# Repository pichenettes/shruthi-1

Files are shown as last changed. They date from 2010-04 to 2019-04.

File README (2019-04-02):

Shruthi-1, a digital/analog hybrid MIDI monosynth.

This project is a redesign of the original Shruti-1, with a spec'ed up CPU,
and a focus on easy upgrades/modification of the analog section.
The ATMega644p allows new features in the firmware -- a larger selection of
oscillator algorithms, a bigger selection of wavetables, and a tiny sequencer.

Original developer: Emilie Gillet (emilie.o.gillet@gmail.com)

The firmware is released under a GPL3.0 license. It includes a
reimplementation of the formant synthesis algorithm used in Peter Knight's
Cantarino speech synthesizer.

The PCB layouts and schematics (in /hardware/shruthi/design/pcb)
are released under a Creative Commons cc-by-sa 3.0 license - except for some
discontinued filter boards which were released under a cc-by-nc-sa 3.0 license.

Documentation, analyses, simulations and 3D models are released under a
Creative Commons cc-by-sa 3.0 license.

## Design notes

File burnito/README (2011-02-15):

Burnito is a firmware for the Shruthi-1 digital board with a very specific
purpose: burn I2C eeproms with Shruthi-1 presets.

This firmware contains a large 16kb blob in flash with the eeprom contents. At
boot, it tries to recognize the size of the eeprom, and writes the relevant
part of this blob to the eeprom. Afterwards, the data is read back from the
eeprom and compared to the original.

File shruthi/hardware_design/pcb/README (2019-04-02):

PCB art:
- "saraswati" by Francois Barbut.
- "peacock_face" by Emilie Gillet.
- "radha" by Emilie Gillet.

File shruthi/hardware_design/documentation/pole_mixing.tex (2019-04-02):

\documentclass[a4paper,10pt]{article}
\usepackage[utf8]{inputenc}
\usepackage[T1]{fontenc}
\usepackage[english]{babel}
\usepackage{times}
\usepackage{graphicx}
\usepackage{tikz}
\usepackage{circuitikz}
\textwidth=6in
\textheight=9.0in
\headheight=0in
\headsep=0in
\oddsidemargin=0in
\evensidemargin=0in
\title{SSM2164 4-pole with pole-mixing}
\author{Émilie Gillet -- \tt emilie.o.gillet@gmail.com}
\date{}
\begin{document}

\maketitle

This document explains the inner workings of the ``Pole mixer" filter board, which uses a SSM2164 4-pole core along with a pole-mixer to realize 15 different transfer functions.

\section{VCA-based 1-pole LPF}

We remind here that a SSM2164 VCA cell works as a voltage-controlled current attenuator, according to the following equation:

$$i_{out} = i_{in} 10^{-\frac{3}{2} v_c}$$

Note that input pin of the SSM2164 is part of a differential pair whose other input is internally grounded (please refer to figure 23 in the SSM2164 datasheet), so the input pin is at ground potential and $i_{in}$ is simply $\frac{v_{in}}{R}$.

Let us model the circuit in figure \ref{fig:vcf} from left to right. The current at the input of the VCA is the sum of the input current, and the current fed back from the output:

\begin{figure}
\begin{center}
\begin{circuitikz} \ctikzset{bipoles/not port/circle width=0}
 \draw
 (0, 0) node[op amp] (opamp) {}
 (opamp.-) node[anchor=south] {$v'_-$}
 (opamp.+) to[short] (-1.5, -0.5)
 (opamp.out) to[short, -] (3, 0)
 (3, 0) node[anchor=south] {$v_o$}
 (-1.5, -0.5) to (-1.5, -1)
 (-1.5, -1) node[ground] {}
 (opamp.-) to[, -*] (-1.5, 0.5)
 (-1.5, 0.5) to (-1.5, 1.5)
 (-1.5, 1.5) to[C, C=$C$, -*] (2, 1.5)
 (2, 1.5) to[short] (2, 0)
 (2, 0) to[*-] (opamp.out)
 (2, 1.5) to (2, 3)
 (2, 3) to[R, R=$R$] (-4.5, 3)
 (-7, 0.5) to[R, R=$R$, i=$i_s$] (-5, 0.5)
 (-5, 0.5) to[short] (-4.5, 0.5)
 (-4.5, 3) to[i=$i_o$, -*] (-4.5, 0.5)
 (-3, 0.5) node[not port] (amp) {}
 (-4.5, 0.5) to[i=$i_{in}$] (amp.in)
 (amp.out) to[i=$i_{out}$] (-1.5, 0.5)
 (-7, 0.5) node[anchor=south] {$v_s$}
 (-3, -1) node[anchor=north] {$v_c$}
 (-3, -1) to (-3, 0.2)
;\end{circuitikz}
\end{center}
\caption{1-pole voltage-controlled low-pass filter based on a VCA cell}
\label{fig:vcf}
\end{figure}

\begin{eqnarray*}
i_{in}(p) &=& i_s(p) + i_o(p) \\
i_{in}(p) &=& \frac{1}{R}(v_s(p) + v_o(p))
\end{eqnarray*}

The op-amp is used as a current to voltage converter (or \emph{transimpedance amplifier}), and is inverting:

\begin{eqnarray*}
v_o(p) &=& -Z_{feedback}(p) i_-(p) \\
v_o(p) &=& -\frac{1}{Cp} i_{out}(p) \\
v_o(p) &=& -\frac{1}{Cp} 10^{-\frac{3}{2} v_c} i_{in}(p) \\
v_o(p) &=& -\frac{1}{Cp} 10^{-\frac{3}{2} v_c} \frac{1}{R}(v_o(p) + v_s(p)) \\
v_o(p) &=& \frac{-\frac{1}{RCp} 10^{-\frac{3}{2} v_c}v_s(p)}{\left(1 + \frac{1}{RCp} 10^{-\frac{3}{2} v_c} \right)}
\end{eqnarray*}

We can now compute the transfert function:

\begin{eqnarray*}
H(p) &=& \frac{v_o(p)}{v_s(p)} \\
H(p) &=& \frac{-1}{1 + RC 10^{\frac{3}{2} v_c} p} \\
\end{eqnarray*}

This is the transfer function of an \textbf{inverting} 1-pole low-pass filter, with a pole at the frequency zeroing the denominator:

\begin{eqnarray*}
1 + RC 10^{\frac{3}{2} v_c} 2 \pi f_c &=& 0 \\
f_c &=& \frac{-1}{2 \pi RC} 10^{-\frac{3}{2} v_c}
\end{eqnarray*}

With $R = 33k\Omega$ (the datasheet suggests $R = 30k\Omega$ for the voltage to current conversion on the SSM2164 inputs), and $C = 220pF$, a frequency range of $22Hz$ to $22kHz$ can be obtained with $v_c$ varying from $2.0V$ to $0.0V$ (the circuit doing this scaling is a simple op-amp in inverter configuration, not detailed here).

In the rest of this document we use the scaled variable $s = RC 10^{\frac{3}{2} v_c} p$ to simplify the transfer function of this 1-pole cell into $\frac{-1}{1 + s}$.

A simple 4-pole filter can be built by chaining 4 1-pole cells. The resulting transfer function is thus $\frac{1}{(1 + s)^4}$.

\section{Pole-mixing}

Pole-mixing consists in mixing, with different gains, the output of each 1-pole cell of a 4-pole filter. Let us call $a, b, c, d$ the gains applied to the output of the first, second, third and fourth cells ; and let us assume that the amplifier doing the summing and amplification is inverting. The resulting transfer function will thus be:

$$H_{a, b, c, d}(s) = \frac{a}{1 + s} + \frac{-b}{(1 + s)^2} + \frac{c}{(1 + s)^3} + \frac{-d}{(1 + s)^4}$$

Notice the alternating signs. This is because our SSM2164 based 1-pole cell is inverting, and this is very helpful indeed as we will see later! A little digression about this: In other pole-mixing circuits such as that of the Oberheim Xpander, additional op-amp stages are needed to buffer the output of each stage, and then to invert the output of each odd stage, requiring up to 6 op-amps to be added to the circuit. Here, the inversion and low-impedance output is built-in the low-pass cell itself, and the only thing to add for the mixing are resistors feeding into the virtual ground of a summing op-amp!

This ``mixed" transfer function can be expanded into:

$$H_{a, b, c, d}(s) = \frac{a s^3 + 3as^2-3as + a - b s^2 - 2bs - b + cs +c - d}{(1 + s)^4}$$

Any 4th order transfer function with $(1 + s)^4$ as its denominator:

$$H_{x, y, z, t}(s) = \frac{x s^3 + y s^2 + z s + t}{(1 + s)^4}$$

can be implemented by pole mixing using the coefficients $a, b, c, d$ which are solutions of these linear equations:

$$\left\{\begin{array}{c}
a = x \\
3a - b = y \\ 
3a - 2b + c = z \\
a - b + c - d = t
\end{array}\right.$$

A bank of resistors behind (a) multiplexer(s) can be used to switch sets of $a, b, c, d$ coefficients. There are still a few problems with this solution though:

\begin{itemize}
\item It would require from 1 to 4 resistors per transfer function we want the filter to implement!
\item Transfer functions like $\frac{s}{1 + s}$ (1-pole HP) are not realizable with this system, since the order of the polynomial at the numerator can only be strictly lower than the order of the polynomial at the bottom.
\end{itemize}

A possible solution is to add a switch in the circuit to bypass the first low-pass cell (or more accurately use a lower integration cap to provide a very high cutoff-frequency). Using this approach, transfer functions of the form:

$$H_{x, y, z, t}(s) = \frac{x s^3 + y s^2 + z s + t}{(1 + s)^3}$$

can also be implemented using the same circuit and the same design equations, with the only change that the first inverting 1-pole cell has been bypassed and replaced by a simple inverting cell.

The second benefit of this ``switched first 1-pole" approach is that it is often the case that if $H(s)$ is an interesting transfer function, $H(s) (1 + s)$ will also be worth considering. Consequently, if a set of mixing resistors has been put in place for $H(s)$, it is trivial to just switch the first LP section off to realize $H(s) (1 + s)$.

\section{The 15 modes}

\subsection{Low-pass modes}

\begin{tabular}{lcclllll}
\hline
Name & Response & Transfer function & $a$ & $b$ & $c$ & $d$ & First LP stage \\
\hline
LP1 &  & $\frac{1}{1 + s}$ & 0 & 1 & 0 & 0 & Disabled \\
\hline
LP2 &  & $\frac{1}{(1 + s)^2}$ & 0 & 1 & 0 & 0 & Enabled \\
\hline
LP3 &  & $\frac{1}{(1 + s)^3}$ & 0 & 0 & 0 & 1 & Disabled \\
\hline
LP4 &  & $\frac{1}{(1 + s)^4}$ & 0 & 0 & 0 & 1 & Enabled \\
\hline
\end{tabular}

\subsection{High-pass modes}

\begin{tabular}{lcclllll}
\hline
Name & Response & Transfer function & $a$ & $b$ & $c$ & $d$ & First LP stage \\
\hline
HP1 &  & $\frac{s}{1 + s}$ & 1 & 1 & 0 & 0 & Disabled \\
\hline
HP2 &  & $\frac{s^2}{(1 + s)^2}$ & 1 & 2 & 1 & 0 & Disabled \\
\hline
HP3 &  & $\frac{s^3}{(1 + s)^3}$ & 1 & 3 & 3 & 1 & Disabled \\
\hline
\end{tabular}

\subsection{Band-pass modes}

\begin{tabular}{lcclllll}
\hline
Name & Response & Transfer function & $a$ & $b$ & $c$ & $d$ & First LP stage \\
\hline
BP2 &  & $\frac{s}{(1 + s)^2}$ & 1 & 1 & 0 & 0 & Enabled \\
\hline
BP4 &  & $\frac{s^2}{(1 + s)^4}$ & 0 & 1 & 2 & 1 & Enabled \\
\hline
\end{tabular}

\subsection{Notch and phaser modes}

\begin{tabular}{lcclllll}
\hline
Name & Response & Transfer function & $a$ & $b$ & $c$ & $d$ & First LP stage \\
\hline
Notch &  & $\frac{s^3 + s^2 + s + 1}{(1 + s)^3}$ & 1 & 2 & 2 & 0 & Disabled \\
\hline
Phaser &  & $1 - \frac{(1 - s)^3}{(1 + s)^3}$ & 1 & 3 & 6 & 4 & Disabled \\
\hline
\end{tabular}

\subsection{``Leftover" modes}

These modes are of little interest, but are cheap to realize by toggling the LP stage on already existing modes.

\begin{tabular}{lcclllll}
\hline
Name & Response & Transfer function & $a$ & $b$ & $c$ & $d$ & First LP stage \\
\hline
HP2 + LP1 &  & $\frac{s^3 + s^2}{(1 + s)^4}$ & 1 & 2 & 1 & 0 & Enabled \\
 & & & 0 & 1 & 2 & 1 & Disabled \\
\hline
HP3 + LP1 &  & $\frac{s}{(1 + s)^4}$ & 1 & 3 & 3 & 1 & Enabled \\
\hline
Notch + LP1 &  & $\frac{s^3 + s^2 + s + 1}{(1 + s)^4}$ & 1 & 2 & 2 & 0 & Enabled \\
\hline
Phaser + LP1 &  & $\frac{1}{1 + s} - \frac{(1 - s)^3}{(1 + s)^4}$ & 1 & 3 & 6 & 4 & Enabled \\
\hline
\end{tabular}

\end{document}

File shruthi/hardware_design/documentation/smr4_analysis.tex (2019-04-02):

\documentclass[a4paper,11pt]{article}
\usepackage[utf8]{inputenc}
\usepackage[T1]{fontenc}
\usepackage[english]{babel}
\usepackage{times}
\usepackage{graphicx}
\textwidth=6in
\textheight=9.0in
\headheight=0in
\headsep=0in
\oddsidemargin=0in
\evensidemargin=0in
\title{Analysis of SMR-4 VCF/VCA board}
\author{Émilie Gillet -- \tt emilie.o.gillet@gmail.com}
\date{}
\begin{document}

\maketitle

The SMR-4 board is the ``default" analog signal processing board for the  Shruthi-1. It includes a 4-pole VCF (presented in section \ref{sec:vcf}) with VC-resonance and a linear VCA (presented in section \ref{sec:vca}). It only makes use of inexpensive and easily available chips.

\section{Generalities}

\subsection{Power}

The board is powered from a non-regulated single supply rail in the 7.5V-15V range. A negative rail is obtained from this by means of a LT1054 DC-DC converter; charged into a $100\mu F$ capacitor -- or $110\mu F$ equivalent when a $10\mu F$ tantalum cap is added in parallel -- and set to a switching frequency of 50kHz. The input positive rail and the negative rail from the LT1054 are regulated by 7x05 linear regulators and generously filtered.

The main advantage of working with +/- 5V rails is that no extra regulator is required for powering the digital section. Furthermore, the device can be powered by a 9V battery, or even a pack of five 1.5V batteries. The main drawback is the smaller headroom for all the op-amps -- the LT074 clips at around $\pm 3.7V$.

\subsection{Input signals}

All input signals, be it the raw oscillators signal or the control voltages, are $0$ / $5V$ PWM signals with a carrier frequency of $\frac{20MHz}{512} = 39062 Hz$.

This implies that the control signals have to be smoothed. You shouldn't feel bad about it: the MCU generates the control signals at a ``slow" rate of $976 Hz$ anyway, so a simple 1-pole low-pass with a cutoff frequency of $1.25 kHz$ kills the PWM carrier by $30dB$ while still tracking fast enough the fastest transitions the MCU can create.

The oscillators signal also has this $39kHz$ carrier. It is attenuated by the main 4-pole LPF itself, and by an extra 1-pole LPF with a fixed cutoff frequency nearing $20kHz$ at the final output buffer. In the worst case (cutoff set to its maximum value), the carrier is thus attenuated by $30dB$. In most cases, however, the cutoff frequency is set to a lower value, and the carrier is attenuated more strongly. Anti-aliasing filters at the input of your soundcard, speakers with a limited bandwidth, or your ears will be doing the rest of the filtering.

\section{VCF}
\label{sec:vcf}

The VCF section consists of a ``CV-scaling" section inverting and scaling the input CV to a range of values suitable for the exponential current source that follows. The exponential current source generates biasing currents for 4 OTA-integrator cells, each of those implementing a 1-pole low-pass filter.

\subsection{OTA-integrator low-pass cell}
\label{sec:otac}

Each ``OTA-integrator" cell of the VCF section follows the template shown in figure \ref{fig:otac}. $R_{20}$ and $R_{30}$, or their counterparts in the other cells, have an identical big value noted $R_b$ ; $R_{22}$ a small value noted $R_s$. $C$ will denote the value of $C_{25}$.

\begin{figure}
\centering

\caption{OTA-integrator low-pass cell.}
\label{fig:otac}
\end{figure}

Let's start by the OTA. Kirchoff in $V_+$ yields:

\begin{eqnarray}
\frac{1}{R_b}(V_{in}(p) - V_+(p)) + \frac{1}{R_b} (V_{out}(p) - V_+(p)) &=& \frac{1}{R_s} V_+(p) \\
V_+(p) &=& \frac{R_s}{R_b + 2 R_s} (V_{in}(p) + V_{out}(p))
\end{eqnarray}

$V_-$ is simply grounded. The current $I_c(p)$ at the output of the OTA is:

\begin{eqnarray}
I_c(p) &=& g_m (V_+(p) - V_-(p)) \\
 &=& 19.2 I_{freq} \frac{R_s}{R_b + 2 R_s} (V_{in}(p) + V_{out}(p))
\end{eqnarray}

The operational amplifier $IC_{8D}$ is in a simple inverting ``current to voltage" configuration:

\begin{eqnarray}
V_{out}(p) &=& - I_c(p) Z_{feedback}(p) \\
 &=& - \frac{I_c(p)}{Cp} \\
 &=& - 19.2 I_{freq} \frac{R_s}{(R_b + 2 R_s)Cp} (V_{in}(p) + V_{out}(p))
\end{eqnarray}

Solving for $V_{out}(p)$ and dividing by $V_{in}(p)$, we find the transfer function:

\begin{eqnarray}
H(p) &=& \frac{-1}{1 + \frac{(R_b + 2 R_s)}{R_s} Cp \frac{1}{19.2 I_{freq}}}
\end{eqnarray}

The pole is at the frequency $f$ such that:

\begin{eqnarray}
0 &=& 1 + \frac{(R_b + 2 R_s)}{R_s} C 2\pi f \frac{1}{19.2 I_{freq}} \\
f &=& -\frac{19.2 I_{freq}}{2 \pi \frac{(R_b + 2 R_s)}{R_s} C}
\end{eqnarray}

At this stage, we can already pick values for $R_b$, $R_s$, $C$ and design the exponential current source so that its current range translate into a target frequency range using the formula above.

The values that have been chosen for $R_b$, $R_s$ and $C$ follow closely those given in the application schematics of the SSM2040 datasheet (Figure 9 of the datasheet):

\begin{eqnarray*}
R_b &=& 10 k \Omega \\
R_s &=& 220 \Omega \\
C &=& 1 nF
\end{eqnarray*}

$R_s = 200 \Omega$ in the SSM2044 datasheet, but we have privileged here values in the E12 series.

\subsection{Exponential current source}

As we've seen in the previous section, the cutoff frequency is proportional to the biasing current $I_{freq}$ of the OTAs. Since we want to achieve an exponential frequency control, we need to produce a control current which is an exponential function of the input CV. This is achieved by the exponential current source in figure \ref{fig:expo}.

\begin{figure}
\centering

\caption{Exponential current source.}
\label{fig:expo}
\end{figure}

Let's start with the core of the circuit -- the NPN transistor pair Q7 and Q8 (we'll see later why NPN instead of PNP). Ebers-Moll for Q7 and Q8 yields the collector currents for both transistors:

\begin{eqnarray}
I_{c7} &=& I_{s7} \left(\exp \left( \frac{V_{be7}}{V_T} \right) - 1 \right) \\
I_{c8} &=& I_{s8} \left(\exp \left( \frac{V_{be8}}{V_T} \right) - 1 \right)
\end{eqnarray}

$V_T$ is the thermal voltage, equal to $26 mV$ at room temperature. We'll see later that $\exp \left( \frac{V_{be7}}{V_T} \right)$ is an order of magnitudes bigger than 1, it is thus a sane approximation to ignore the $- 1$ term. Assuming that the transistor have the same characteristics, $I_{s7} = I_{s8}$. Thus we have, by substituting in the second equation the value of $I_{s8}$ derived from the first one:

\begin{equation}
I_{c8} = I_{c7} \exp \left( \frac{V_{be8} - V_{be7}}{V_T} \right)
\end{equation}

Since the base of $Q8$ is grounded, and since the emitter of $Q7$ and $Q8$ are at the same potential:

\begin{equation}
I_{c8} = I_{c7} \exp \left( -\frac{V_{freq}}{V_T} \right)
\end{equation}

The value of $I_{c8}$ is simply:

\begin{equation}
I_{c8} = \frac{V_{cc} - V_a}{R_{47}} = \frac{V_{cc}}{R_{47}}
\end{equation}

$V_a$ is null because the point $A$ is virtually grounded. Indeed, the whole point of the operational amplifier $IC_{3B}$ is to keep the point $A$ at a constant potential. $C_{13}$ is only here to stabilize the op-amp. $R_{46}$ works as a current limiter -- we can compute its value later to make sure that the maximum current $I_{c8}$ translates into a reasonable frequency.

Note that the biasing current $I_{c8}$ varies in the inverse direction of $V_{freq}$~-- when $V_{freq}$ increases, $I_{c8}$ decreases. This is not a problem because $V_{freq}$ is generated by an op-amp in an inverting configuration.

This brings us to discuss the roles of $Q4$ (and $Q3$, $Q5$, $Q6$). If $I_{c8}$ was directly used as a biasing current for the OTA, the circuit wouldn't work at all, because the biasing current pin of the LM13700 is not ``pointing" in the right direction. A way of avoiding this problem would be to simply replace $Q_7$ and $Q_8$ by PNP ; but if we do so, $I_{c8}$ varies in the same direction as $V_{freq}$, and this means that the CV-scaling stage described in the next section should not invert the input signal. This leaves 3 options:

\begin{itemize}
\item Design the CV-scaling stage as a non-inverting summer. This doesn't work well because the op-amp in such a non-inverting configuration has a gain above $1$, while the scaling we want to achieve requires a gain lower than $1$. You can also observe that the input voltage being in the $0-5V$ range ; and the op-amps being powered by $\pm 5V$, using a circuit with a gain above 1 will result in clipping.
\item Add a simple inverting amplifier with a gain of 1 at the output of the (inverting) summer ; or more generally design the CV-scaling circuit with two inverting stages. This is an option frequently seen (e.g. Polyfusion) ; but the constraints on the board size made it impractical.
\item Use an entirely passive CV-scaling circuit, with $V_{freq}$ being the summing node. This solution has also been seen in a couple of circuits erring on the minimalistic side (e.g. EFM wildcat, VCF 1 and 2). The main reason why this solution was rejected is that the Shruthi-1 generates PWM control signals, which need to be filtered -- so the CV-scaling stage also needs to have a low-pass filter. The ``no-summing op-amp" approach requires the use of a passive filter, which, in our experiments poured too much high-frequency noise on the ground.
\end{itemize}

None of those solutions being particularly appealing\footnote{There seems to be a fourth solution we have not verified, and which requires no extra inversion~-- use PNPs, ground the base of $Q7$ and apply the control voltage to the base of $Q8$.}, we decided to stick to NPNs for the core exponential converters, and then use PNPs to ``replicate" the generated current, with the right direction. The circuit thus uses 2 NPN for the core exponential converter, and 1 PNP per pole, instead of 1 PNP for the core exponential converter and 1 PNP per pole. This extra transistor proved to be easier to lay out and cheaper than an extra TL071.

One thing not discussed here is temperature compensation. While the main temperature dependent factors (saturation currents) have been neutralized by the ``resistor pair" design (as long as the transistors are matched and thermically coupled), there remains a temperature dependent term, $V_T$. This term is not compensated. A rough estimate of the variation in frequency is less than $\pm 10\%$ for a change in temperature of $\pm 5^oC$~-- not good for a VCO, but ok-ish for a VCF.

\subsection{CV scaling}

The CV scaling stage is fed with a 0/5V PWM signal generated by the microcontroller, and generates a scaled voltage which will translate into an appropriate cutoff frequency range. In addition to the scaling itself, it also actively smoothes the high-frequency PWM control signal into a near-DC voltage. Its schematics is given in figure \ref{fig:cvscale}.

\begin{figure}
\centering

\caption{CV-scaling.}
\label{fig:cvscale}
\end{figure}

The voltage at the output of the op-amp is given by:

\begin{equation}
V_o(p) = -\frac{R_{19}}{R_{28} + R_{34}} V_{ee} -\frac{Z_f(p)}{R_{29} + R_{35}} V_{fin}(p)
\end{equation}

Where $Z_f(p)$ is the equivalent impedance of the feedback loop, consisting of $R_{19}$ in parallel with $C_{11}$. Note that in the first term, this impedance is simply $R_{19}$ since a capacitor in parallel with a resistor has no effect on DC currents. In the second term, it is equal to:

\begin{equation}
Z_f(p) = \frac{R_{19}}{1 + R_{19}C_{11}p}
\end{equation}

Thus, the cutoff frequency of the filter smoothing the PWM control signals is $\frac{1}{2 \pi R_{19}C_{11}} = 861.7 Hz$ with values given on the schematics. This means that the PWM carrier is attenuated by $6\log_2 \frac{39062}{861.7} = 33dB$. Given this (moderately) high attenuation factor, it is safe to consider that when the cutoff value is constant, the circuit behaves as if $V_{fin}$ is a pure DC component in the $[0, 5]V$ range instead of a PWM signal.

Adding the contribution of the voltage divider comprised of $R_{44}$ and $R_{45}$, we find:

\begin{equation}
V_{freq} = \frac{R_{45}}{R_{45} + R_{44}} \left(-\frac{R_{19}}{R_{28} + R_{34}} V_{ee} -\frac{R_{19}}{R_{29} + R_{35}} V_{fin}\right)
\end{equation}

\subsection{Component values}

\subsubsection{Constraints}

How are the different values of the component selected? From the past sections, some characteristics of the ICs used in the circuit, and some common sense, we can gather a set of constraints ($\sim$ denotes an order of magnitude in this section) the component values must satisfy:

\paragraph{Input impedance} The input impedance of the CV scaling circuit $R_{35} + R_{29}$ shouldn't be too low, at least $\sim 10k \Omega$.

\paragraph{OTA small voltage constraint} The signal at the input of the OTA should not exceed $\sim 10mV pp$.

\paragraph{OTA small biasing current constraint} The biasing current of the OTA should not exceed $\sim 1mA$.

\paragraph{Cutoff frequency constraint} The frequency range of the filter must span the audible spectrum ($20 Hz$ to $20kHz$), and it should be easy to ``tune" it to the fundamental frequency of the oscillators. To this effect, we have decided to eschew the $1 V/octave$ standard (which would have given a very narrow frequency range given that the input signal is in the $[0, 5]V$ range, and to use another approach.

By default (in the ``init" patch), the Shruthi-1 patches the ``note" modulation source to the ``cutoff" modulation destination, with an amount of 63 corresponding to an (almost) unitary modulation. In other words, if the base cutoff setting of the Shruthi-1 is set to $n$, the PWM control signal corresponds to a smoothed DC voltage of:

\begin{equation}
V_{fin} = V_{cc} \frac{n + \mbox{Midi note number} - 64}{128}
\end{equation}

From this, it appears that if we want a 1:1 tracking of the filter frequency to the fundamental frequency of the oscillators, the cutoff frequency should be multiplied by a semitone ($2^\frac{1}{12}$) every time the Midi note number is increased by $1$, that is to say everytime $V_{fin}$ steps by a $\frac{5}{128}$ increment. This yields the rather odd scale of $0.46875V.oct^{-1}$, which is the target $V.oct^{-1}$ scale of the filter.

The filter is thus expected to cover a range of $\frac{128}{12} = 10.66$ octaves~-- the highest cutoff value will be 1625 the lowest cutoff value. The $12.3 Hz$ -- $20kHz$ range has this exact ratio, spans the audible range, and is, incidentally, exactly one fifth above the range of the notes described by the MIDI standard (the lowest note has a fundamental frequency of $8.18 Hz$. One fifth above: $12.27 Hz$).

\paragraph{Pragmatic constraints} Resistor values should be preferably in the E12 series ; and the number of distinct component values should be minimized.

How to find a solution meeting all these constraints? We went the nerdy way and used a constraint solver (implemented in Python, hopefully, to be released later) to search for sets of solutions matching these constraints.

We provide in the rest of this section a validation of the selected values.

\subsubsection{Validation}

\paragraph{Input impedance} Greater than $30k\Omega$, all good!

\paragraph{OTA small voltage constraint} The signal output by the digital oscillator is in the $0-5V$ range, then AC-coupled and scaled by a gain of $0.33$ in the input mixer. The signal at the input of the OTA-C cells has thus a range of $\frac{R_s}{R_b + R_s} \times 0.33 \times 5 = 35mV$.

\paragraph{OTA small current constraint} The worst case corresponds to the maximum cutoff value, which can be obtained with an input signal $V_{fin} = 5V$, $R_{35}$ trimmed to 0, and $R_{34}$ trimmed to $20k\Omega$. In this case, $V_{freq} = 128mV$ and $I_{freq} = 2mA$, small enough to avoid destroying the LM13700.

\paragraph{Frequency range} Let us check first that the lowest cutoff frequency attainable with the filter is in the expected range. $V_{fin}$ is set to $0V$. Depending on how $R_{34}$ is trimmed, we have:

\begin{eqnarray}
-113mV \leq &V_{freq}& \leq -83mV \\
0.19\mu A \leq &I_{freq}& \leq 0.60\mu A \\
12Hz \leq &f& \leq 39Hz
\end{eqnarray}

The target lowest frequency is attained exactly when the trimmer is at its zero position. Keeping this trimmer setting, let us check what is the maximum cutoff frequency that can be reached. $V_{fin}$ is now set to $5V$. Depending on how $R_{35}$ is trimmed, we have:

\begin{eqnarray}
68mV \leq &V_{freq}& \leq 98mV \\
0.208 mA \leq &I_{freq}& \leq 0.669 mA \\
13.3kHz \leq &f& \leq 43.1kHz
\end{eqnarray}

The target frequency range is thus feasible. Now there's a secret: from a pure theoretical point of view, one can get away with the trimmers and replace $R_{29}$ by a $33k\Omega$ resistor (nice value!)~-- which is the original solution the constraint solver yielded~-- and one will find a theoretical frequency range of $12.3 Hz$ to $20.5kHz$, which is dead on. Things did not turn that well in reality due to the wild tolerances of capacitors, and (possibly) the fact that the transistors were not matched. For this reason only, trimmers were added.

\section{VCA and resonance feedback loop}
\label{sec:vca}

TODO

\section{Future work}

\begin{itemize}
\item Stricter temperature compensation on the exponential converter.
\item Try the ``PNP + swapped $Q7$/$Q8$" trick to avoid the extra transistors in the exponential converter.
\end{itemize}

\end{document}

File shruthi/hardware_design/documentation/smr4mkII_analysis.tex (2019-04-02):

\documentclass[a4paper,11pt]{article}
\usepackage[utf8]{inputenc}
\usepackage[T1]{fontenc}
\usepackage[english]{babel}
\usepackage{times}
\usepackage{graphicx}
\textwidth=6in
\textheight=9.0in
\headheight=0in
\headsep=0in
\oddsidemargin=0in
\evensidemargin=0in
\title{Analysis of the SMR-4 VCF/VCA board\\Second revision}
\author{Émilie Gillet \\ \tt emilie.o.gillet@gmail.com}
\date{}
\begin{document}

\maketitle

The SMR-4 mkII board is the second revision of the ``default" analog signal processing board for the  Shruthi-1. It includes a 4-pole VCF (presented in section \ref{sec:vcf}) with VC-resonance and a linear VCA (presented in section \ref{sec:vca}); and only makes use of inexpensive and widely available ICs.

\section{Generalities}

\subsection{Power}

The board is powered from a non-regulated single supply rail in the 7.5V-15V range. A negative rail is obtained from this by means of a LT1054 DC-DC converter; charged into a $100\mu F$ capacitor -- or $110\mu F$ equivalent when a $10\mu F$ tantalum cap is added in parallel -- and set to a switching frequency of 50kHz. The input positive rail and the negative rail from the LT1054 are regulated by 7805/7905 linear regulators and generously filtered.

The main advantage of working with +/- 5V rails is that no extra regulator is required for powering the digital section. Furthermore, the device can be powered by a 9V battery, or even a pack of five 1.5V batteries. The main drawback is the smaller headroom for all the op-amps -- the LT074 clips at around $\pm 3.7V$.

\subsection{Input signals}

All signals generated by the Shruthi-1 digital control board, be it the raw oscillators signal or the control voltages, are $0$ / $5V$ PWM signals with a carrier frequency of $\frac{20MHz}{510} = 39215 Hz$.

This implies that the control signals have to be smoothed. You should not feel bad about it: the MCU generates the control signals at a ``slow" rate of $980 Hz$ anyway, so a simple 1-pole low-pass with a cutoff frequency of $723 Hz$ kills the PWM carrier by $35dB$ while still tracking fast enough the fastest transitions the MCU can create.

The oscillators signal also contains this $39kHz$ carrier. The carrier is attenuated by the main 4-pole LPF itself, and to some extent by the excessively large ``stability" caps in the mixer and VCA I to V converters. In the worst case (cutoff set to its maximum value), the carrier is thus attenuated by $30dB$. In most cases, however, the cutoff frequency is set to a lower value, and the carrier is attenuated more strongly. Anti-aliasing filters at the input of your soundcard, speakers with a limited bandwidth, or your ears will be doing the rest of the filtering. This residual of the PWM carrier might however cause a bit of parasitic hiss if the output signal is fed into a ``vintage" sampler of FX processor with no anti-aliasing filter (the frequency of the hiss being dependent on the difference between the sampling rate and $39kHz$).

All those considerations are not relevant when the SMR-4 is used with another signals source than the Shruthi-1 control board -- but keep in mind that the CV smoothing in place might make things like audio-range filter FM sound differently from what you expect.

\section{VCF}
\label{sec:vcf}

The VCF section consists of a ``CV-scaling" section inverting and scaling the input CV to a range of values suitable for the exponential current source that follows. The exponential current source generates biasing currents for 4 OTA-integrator cells, each of those implementing a 1-pole low-pass filter.

\subsection{OTA-integrator low-pass cell}
\label{sec:otac}

Each ``OTA-integrator" cell of the VCF section follows the template shown in figure \ref{fig:otac}. $R_{37}$ and $R_{39}$, or their counterparts in the other cells, have an identical big value noted $R_b$ ; $R_{35}$ a small value noted $R_s$. $C$ will denote the value of $C_{33}$.

\begin{figure}
\centering

\caption{OTA-integrator low-pass cell.}
\label{fig:otac}
\end{figure}

Let us start by the OTA. Kirchoff in $V_+$ yields:

\begin{eqnarray}
\frac{1}{R_b}(V_{in}(p) - V_+(p)) + \frac{1}{R_b} (V_{out}(p) - V_+(p)) &=& \frac{1}{R_s} V_+(p) \\
V_+(p) &=& \frac{R_s}{R_b + 2 R_s} (V_{in}(p) + V_{out}(p))
\end{eqnarray}

$V_-$ is simply grounded. The current $I_c(p)$ at the output of the OTA is:

\begin{eqnarray}
I_c(p) &=& g_m (V_+(p) - V_-(p)) \\
 &=& 19.2 I_{freq} \frac{R_s}{R_b + 2 R_s} (V_{in}(p) + V_{out}(p))
\end{eqnarray}

The operational amplifier $IC_{7A}$ is in a transimpedance configuration:

\begin{eqnarray}
V_{out}(p) &=& - I_c(p) Z_{feedback}(p) \\
 &=& - \frac{I_c(p)}{Cp} \\
 &=& - 19.2 I_{freq} \frac{R_s}{(R_b + 2 R_s)Cp} (V_{in}(p) + V_{out}(p))
\end{eqnarray}

Solving for $V_{out}(p)$ and dividing by $V_{in}(p)$, we find the transfer function:

\begin{eqnarray}
H(p) &=& \frac{-1}{1 + \frac{(R_b + 2 R_s)}{R_s} Cp \frac{1}{19.2 I_{freq}}}
\end{eqnarray}

The pole is at the frequency $f$ such that:

\begin{eqnarray}
0 &=& 1 + \frac{(R_b + 2 R_s)}{R_s} C 2\pi f \frac{1}{19.2 I_{freq}} \\
f &=& -\frac{19.2 I_{freq}}{2 \pi \frac{(R_b + 2 R_s)}{R_s} C}
\end{eqnarray}

At this stage, we can already pick values for $R_b$, $R_s$, $C$ and design the exponential current source so that its current range translate into a target frequency range using the formula above.

The values which have been chosen for $R_b$, $R_s$ and $C$ follow closely those given in the application schematics of the SSM2040 datasheet (Figure 9 of the datasheet):

\begin{eqnarray*}
R_b &=& 10 k \Omega \\
R_s &=& 220 \Omega \\
C &=& 1 nF
\end{eqnarray*}

$R_s = 200 \Omega$ in the SSM2044 datasheet, but we have privileged here values in the E12 series.

\subsection{Exponential current source}

As explained in the previous section, the cutoff frequency is proportional to the biasing current $I_{freq}$ of the OTAs. Since we want to achieve an exponential frequency control, we need to produce a control current which is an exponential function of the input CV. This is achieved by the exponential current source in figure \ref{fig:expo}.

\begin{figure}
\centering

\caption{Exponential current source.}
\label{fig:expo}
\end{figure}

Let us start with the core of the circuit -- the PNP transistor pair $Q_2$ and $Q_3$. The Ebers-Moll equations for $Q_2$ and $Q_3$ give the collector currents for both transistors:

\begin{eqnarray}
I_{c2} &=& I_{s2} \left(\exp \left( \frac{V_{eb2}}{V_T} \right) - 1 \right) \\
I_{c3} &=& I_{s3} \left(\exp \left( \frac{V_{eb3}}{V_T} \right) - 1 \right)
\end{eqnarray}

$V_T$ is the thermal voltage, equal to $26 mV$ at room temperature. We have $|V_{e2}| < 200mV$ (we will see later that this is the range giving cutoff frequencies in the audio range), $V_{b2} \simeq 0.7V$ (1 diode drop) ; so $V_{eb2} >> V_T$. It is thus a sane approximation to ignore the $- 1$ term. Assuming that the two transistors have the same characteristics, $I_{s2} = I_{s3}$. Thus we have, by substituting in the first equation the value of $I_{s2}$ derived from the second one:

\begin{equation}
I_{c2} = I_{c3} \exp \left( \frac{V_{eb2} - V_{eb3}}{V_T} \right)
\end{equation}

Since the base of $Q3$ is grounded, and since the emitters of $Q_2$ and $Q_3$ are at the same potential:

\begin{equation}
V_{eb2} - V_{eb3} = V_{e2} - V_{b2} - V_{e3} + V_{b3} = -V_{b2} = -V_{freq}
\end{equation}

The value of $I_{c3}$ is simply:

\begin{equation}
I_{c3} = \frac{V_{ee} - V_{c3}}{R_{13}} = \frac{V_{ee}}{R_{13}}
\end{equation}

$V_{c3}$ is null because the collector of $Q_3$ is virtually grounded. Indeed, the whole point of the operational amplifier $IC_{4C}$ is to keep the collector of $Q_3$ at a constant potential. $C_{11}$ is only here to stabilize the op-amp. $R_{12}$ works as a current limiter; we can assume that it has no influence in normal operation.

To summarize the previous steps:

\begin{equation}
I_{freq} = -\frac{V_{ee}}{R_{13}} \exp \left(\frac{-V_{freq}}{V_T} \right)
\end{equation}

Observe that the biasing current $I_{freq}$ varies in the inverse direction of $V_{freq}$~-- when $V_{freq}$ increases, $I_{freq}$ decreases. This is not a problem because $V_{freq}$ is generated by an op-amp in an inverting configuration.

One thing not discussed here is temperature compensation. While the main temperature dependent factors (saturation currents) have been neutralized by the ``transistor pair" design (as long as the transistors are of a similar kind and thermically coupled), there remains a temperature dependent term, $V_T$. This term is not compensated. A rough estimate of the variation in frequency is less than $\pm 10\%$ for a change in temperature of $\pm 5^oC$~-- not good for a VCO, but acceptable for a VCF.

\subsection{CV scaling}

The CV scaling stage is fed with a 0/5V PWM signal generated by the microcontroller, and generates a scaled voltage which will translate into an appropriate cutoff frequency range. In addition to the scaling itself, this stage also actively smoothes the high-frequency PWM control signal into a near-DC voltage. The schematics of this stage are given in figure \ref{fig:cvscale}.

\begin{figure}
\centering

\caption{CV-scaling.}
\label{fig:cvscale}
\end{figure}

The voltage at the output of the op-amp is given by:

\begin{equation}
V_{freq}(p) = -\frac{R_{25}}{R_{24}} V_{ee} -\frac{Z_f(p)}{R_{20} + R_{23}} V_{fin}(p)
\end{equation}

Where $Z_f(p)$ is the equivalent impedance of the feedback loop, consisting of $R_{25}$ in parallel with $C_{20}$. Note that in the first term, this impedance is simply $R_{25}$ since the capacitor in parallel with the resistor has no effect on DC currents. In the second term, it is equal to:

\begin{equation}
Z_f(p) = \frac{R_{25}}{1 + R_{25}C_{20}p}
\end{equation}

Thus, the cutoff frequency of the filter smoothing the PWM control signals is $\frac{1}{2 \pi R_{25}C_{20}} = 329 Hz$ with the values given on the schematics. This means that the PWM carrier is attenuated by $6\log_2 \frac{39215}{329} = 40dB$. Given this (moderately) high attenuation factor, it is safe to consider that when the cutoff value is constant, the circuit behaves as if $V_{fin}$ is a pure DC component in the $[0, 5]V$ range instead of a PWM signal.

Note that the use of a supply rail ($V_{ee}$) to generate a negative reference voltage is not a very good practice. This makes the circuit vulnerable to ripples/noise in the negative rail ; and requires accurate voltage regulators. In practice, we have not observed significant noise/ripples on the negative rail ; and small random fluctuations of the cutoff are much less perceptible than noise.

\subsection{An important consideration}

All the computations in the previous steps are done under the assumption that the exponential current source is connected to only one OTA. In the SMR4 mkII filter, the exponential converter is connected to 4 OTAs. Assuming the OTAs have similar characteristics, the biasing current $I_{freq}$ received by each OTA is only one fourth of the value of $I_{c2}$. A more common solution seen in other designs is to duplicate 4 times the left side of figure \ref{fig:expo}. Not doing so saves 3 transistors but has a drawback: in case one of the OTA cells fails, the current received by the other cells will be higher. This put a constraint on the current limiting resistor $R_{12}$: if it is too low, the maximum current emitted by the exponential converter will be acceptable for 4 cells but not for 2 or 3 in case of failure ; and if it is too high, the maximum current will not give a sufficiently high cutoff frequency.

\subsection{Component values}

\subsubsection{Constraints}

How are the different values of the component selected? From the past sections, some characteristics of the ICs used in the circuit, and some common sense, we can gather a set of constraints the component values must satisfy:

\paragraph{Input impedance} The input impedance of the CV scaling circuit $R_{23} + R_{34}$ should not be too low, at least $10k \Omega$.

\paragraph{OTA small biasing current constraint} The biasing current of the OTA should not exceed $2mA$.

\paragraph{Cutoff frequency constraint} The frequency range of the filter must span the audible spectrum ($20 Hz$ to $20kHz$), and it should be easy to ``tune" it to the fundamental frequency of the oscillators. To this effect, we have decided to eschew the $1 V/octave$ standard (which would have given a very narrow frequency range given that the input signal is in the $[0, 5]V$ range, and to use another approach.

In the Shruthi-1 firmware, the filter tracking code works the following way: the MIDI note value (an integer between 0 and 127) minus 64 is added to the filter cutoff value (which is itself represented as a 7-bit integer). In other words, if the base cutoff setting of the Shruthi-1 is set to $n$, the PWM control signal corresponds to a smoothed DC voltage of:

\begin{equation}
V_{fin} = V_{cc} \frac{n + \mbox{Midi note number} - 64}{128}
\end{equation}

From this, it appears that if we want a 1:1 tracking of the filter frequency to the fundamental frequency of the oscillators, the cutoff frequency should be multiplied by a semitone ($2^\frac{1}{12}$) every time the Midi note number is increased by $1$, that is to say every time $V_{fin}$ steps by a $\frac{5}{128}$ increment. This yields the rather odd scale of $0.46875V.oct^{-1}$, which is the target $V.oct^{-1}$ scale of the filter.

The filter is thus expected to cover a range of $\frac{128}{12} = 10.66$ octaves~-- the highest cutoff value will be 1625 times the lowest cutoff value. The $14.9 Hz$ -- $22.8kHz$ range has this exact ratio and spans the audible range.

\paragraph{Pragmatic constraints} Resistor values should be preferably in the E12 series ; and the number of distinct component values should be minimized.

\subsubsection{Validation}

We provide in the rest of this section a validation of the selected values.

\paragraph{Input impedance} Greater than $47k\Omega$, all good!

\paragraph{OTA small current constraint} At worst, the output of $IC4C$ is $3.7V$ (clipping output voltage for a $TL074$) ; and we have $V_{e2} = V_{e3} = 0.7V$. The maximum current produced by the exponential converter is thus $3.0mA$ with $R_{12} = 1k\Omega$. This is enough to protect one of the LM13700 (2 OTA cells) in case the other one is not inserted in its socket.

\paragraph{Cutoff frequency range} Let us check first that the lowest cutoff frequency attainable with the filter has the expected value. When $V_{fin} = 0V$, $V_{freq} = -73mV$ and $I_{freq} = 0.23\mu A$. The lowest cutoff frequency is thus: $14.5 Hz$.

Let us now check what is the maximum cutoff frequency that can be reached. $V_{fin}$ is now set to $5V$. Depending on how $R_{34}$ is trimmed, we have:

\begin{eqnarray}
0 \Omega \leq &R_{34}& \leq 20 k\Omega \\
91mV \leq &V_{freq}& \leq 161mV \\
0.125 mA \leq &I_{freq}& \leq \frac{3.0}{4} mA \\
8kHz \leq &f& \leq 48kHz
\end{eqnarray}

The target frequency range is thus feasible. Note that the exact 1:1 tracking is achieved with $R_{34} = 10.2 kHz$, so the default factory position of the trimmer (middle) is roughly the right one.

\section{VCA}
\label{sec:vca}

\subsection{Linear current source}

The linear current source in figure \ref{fig:linear} generates the biasing current for the VCA OTA cell. Let us make a few assumptions:
\begin{itemize}
\item The input signal is DC, and thus, $C9$ has no effect (actually its purpose is to smooth the output).
\item $Q_1$ has an $\alpha$ equal to 1, which implies that $I_{gain} = I_{c1} = I_{e1}$.
\item The op-amp is not operating in saturation mode, which implies that $V_- = V_+ = 0$.
\item The op-amp has infinite input impedance, which implies that $I_- = 0$.
\end{itemize}

\begin{figure}
\centering

\caption{Linear current source.}
\label{fig:linear}
\end{figure}

Thus, we have:

\begin{equation}
I_{gain} = I_{e1} = I_{R8} = \frac{V_{gain}}{R_9} + \frac{V_{ee}}{R_{10}}
\end{equation}

Intuitively, this circuit works the following way: through feedback, the op-amp ensures that the current flowing through $R_8$ is the same as the input current at the summing node -- it does so by controlling the base voltage of $Q_1$. It is as if the op-amp is solving the Ebers-Moll equation for $V_{b1}$ to give the target $I_{e1}$!

$I_{gain}$ is thus directly proportional to $V_{gain}$. The additional offset term $\frac{V_{ee}}{R_{10}}$ helps ``silencing" the VCA -- the reason behind this is that the Shruthi-1 control board cannot actually output null voltages -- when a PWM output on the MCU is set to 0 it outputs a few $mV$. $R_{10}$ can be left unpopulated.

Observe that $R_8$ ; in conjunction with the op-amp's clipping ; can play the role of a current limiter on the output current, yielding a kind of reverse-exponential response with a ``knee" when the op-amp starts failing to set its output high or low enough to guarantee that a large enough current flows through the transistor. The value chosen here is low enough to not cause current limiting.

\subsection{Current controlled amplifier}

\begin{figure}
\centering

\caption{Current controlled amplifier.}
\label{fig:vca}
\end{figure}

The schematics in figure \ref{fig:vca} represents a current controlled amplifier.

$C5$ AC-couples the input. Assuming the input signal $VCA\_IN$ has no DC-offset, this capacitor can be ignored. The voltage at the inverting input of the OTA is:

\begin{equation}
V_- = \frac{R_6}{R_6 + R_7} VCA\_IN
\end{equation}

The current at the output of the OTA is:

\begin{eqnarray}
V_o &=& g_m (V_+(p) - V_-(p)) \\
 &=& -19.2 I_{gain} \frac{R_6}{R_6 + R_7} VCA\_IN
\end{eqnarray}

Finally, this current is converted into a voltage through $IC2B$ which works as a transimpedance amplifier:

\begin{equation}
VCA\_OUT = -R_5 V_o
\end{equation}

Using all these, the gain of the VCA is:

\begin{equation}
G = 19.2 R_5 \frac{R_6}{R_6 + R_7} \left(\frac{V_{gain}}{R_9} + \frac{V_{ee}}{R_{10}}\right)
\end{equation}

This yields a gain of $2$ when the $V_{gain}$ control signal is equal to its maximum value of $5V$.

\section{Resonance control}

Resonance is achieved by feeding back a fraction of the filter output signal into the filter input. Traditionally, this is done through a potentiometer (voltage divider). Here, in order to provide voltage control over resonance, we use a VCA similar in design to that of the main signal VCA. There are two important differences in the design:

First, the current output by the OTA is not converted back into a voltage by an op-amp. Instead, it is directly injected at the summing node of the first OTA-integrator cell. A way to look at it: the $220 \Omega$ resistor to ground at the OTA-integrator cell inverting input does the current to voltage conversion.

Then, the resonance VCA is fed not only with the filter output, but also with a fraction of the unfiltered input signal itself. This causes the level of the signal entering the filter to increase as resonance is increased, and helps in compensating the dreaded ``resonance loudness drop" of 4-pole filters. An extra refinement here is that the the input signal is coupled into the resonance VCA through an undersized capacitor. This will cause the resonance loudness drop to be compensated only in the highest regions of the spectrum ; creating brighter and shinier sounds when the resonance is increased. This trick was inspired by the Jupiter-8 filter circuit.

\section*{Foreword: learning from mistakes}

18 months and roughly 1000 units have happened between the design of the original filter (which was my first shot at doing analog synth circuits) and this revision. This section briefly discusses some of the changes:

\begin{itemize}
\item The main ``awkwardness" in the original design was the exponential converter. All the calculations had been done with a pair of NPN; until I realized in shock that the current biasing pin on the LM13700 is below ground. My attempt to save the design with PNPs ``mirroring" the current from the exponential converter was rather inelegant.
\item During the design of the first version, many efforts had been done to get all the part values exactly right, which sometimes requested additional voltage dividers to get required voltage ratios using E12 or E24 values -- this can be seen in the filter cutoff CV scaler. This ultimately proved futile as some parts have rather wide tolerances (at best 2.5\% for capacitors); and thus came the trimmers.
\item \textbf{Trimmers are evil, do not use them}. Some builders are obsessed by them and are chasing a magical combination of settings giving ``the perfect sound". They distract the attention of some builders trying to identify a build problem; while some builders having committed grave assembly mistakes do not bother fixing them because they wrongly assume the bad sound comes from inadequate trimming. Finally, giving choices to users is not very compatible with the diffusion and sharing of patch libraries (``how my patch will sound on someone else's device which has a different cutoff range?"). I am now keeping trimmers for the strict minimum -- V/Oct -- tuning and would rather rely on sane defaults even if they are at $\pm 5\%$.
\item I made a point of having a DC-coupled VCA in the first version to have the flattest response in the low-end. This requested the adjustment of a trimmer to compensate for a slight DC offset at the output of the filter -- and I suspect that a significant proportion of builders ignored it or got it wrong. I am no longer scared of AC-coupling and losing half a dB at 10 Hz.
\item On the original filter, the compensation for the resonance loudness drop was done at the final VCA. Here it is done directly within the resonance VCA - a simpler design I learnt from looking at the schematics of IR3109-based filters.
\item The original design had a few ``current to voltage to current" blocks that came from piecing together basic bits of circuits but could ultimately be eliminated.
\item Some better choices of parts: DC jacks with thick legs (easier to source), trimmers with side adjustment (trimming can be done without disassembling the unit), $0.1in$ space solder pads for pots.
\end{itemize}

To conclude, a list of things that did not work well during the design of this filter and that I had to throw away:

\begin{itemize}
\item Unipolar power supply and virtual ground. In my quest of getting rid of the expensive LT1054, I worked on a first design with a 9V unipolar supply and a virtual ground. In spite of trying many different techniques for getting a clean middle rail (buffered rail splitter IC ; precision voltage reference ; voltage regulator), noise was always a problem and the virtual ground circuit always performed 5 or 6 dB worse than its split supply equivalent. Even with copious (to the point of being more expensive than a LT1054) decoupling. Worst part: those super useful 9V PP3 battery to 2.1mm jack clips could not be used, since an input voltage above 11V had to be provided to the filter board.
\item AC power supply. What's more expensive than a LT1054? A pair of heatsinks and big caps.
\item LM13700 Darlington buffers. The ``OTA-C-buffer" configuration is actually very common, but I could not get it to work with the LM13700 Darlingtons in a satisfying way. The main problem was self-oscillation, which, for different values of the cutoff frequency, did not appear at the same values of the resonance VCA gain. Either a loud, Curtis-like, distorted sine wave for high cutoff values and a normal sine wave for the lowest values ; or a normal sine wave for high cutoff values and no self-oscillation for the lowest values. It was as if the Darlington buffers had a slight high-pass effect.
\item LM13700 linearization diodes. Where's the fun gone?
\end{itemize}

\end{document}

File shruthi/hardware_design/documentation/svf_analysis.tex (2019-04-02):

\documentclass[a4paper,11pt]{article}
\usepackage[utf8]{inputenc}
\usepackage[T1]{fontenc}
\usepackage[english]{babel}
\usepackage{times}
\usepackage{graphicx}
\textwidth=6in
\textheight=9.0in
\headheight=0in
\headsep=0in
\oddsidemargin=0in
\evensidemargin=0in
\title{SSM2164 SVF}
\author{Émilie Gillet -- \tt emilie.o.gillet@gmail.com}
\date{}
\begin{document}

\maketitle



\section{Theory}

Notations:

$R_i$ is the value of the resistor through which the input signal is fed to the circuit.

$R_g$ is the value of the resistors through which the HP and LP outputs are fed back into the input.

$R_q$ is the value of the resistor through which the attenuated BP output is fed back into the input.

$R$ is the value of the resistors through which input voltages are converted into currents at the input of the 2164s, and through which the current at the output of the Q attenuator is converted back into a voltage.

$C$ is the value of the integrators' capacitors.

$v_{cv}$ is the cutoff frequency control voltage and $v_{q}$ is the reso control voltage.

The input voltage is $v_i(s)(s)$. $v_{lp}(s)$, $v_{hp}(s)$, $v_{bp}(s)$ are respectively the voltages at the low-pass, high-pass and band-pass nodes of this circuit.

As a reminder, the transfer function of a SSM2164 gain cell is $i_{out} = i_{in} 10^{-\frac{3}{2} v_{cv}}$. The transfer function of an integrator cell $\alpha$ is thus the following:

\begin{equation}
\alpha(s) = -\frac{1}{RCs} 10^{-\frac{3}{2} v_{cv}}
\end{equation}

We also have: $v_{bp}(s) = v_{hp}(s) \alpha(s)$, and $v_{lp}(s) = v_{hp}(s) \alpha^2(s)$.

The gain of the feedback circuit is noted $\beta$:

\begin{equation}
\beta = \frac{1}{R} 10^{-\frac{3}{2} v_{q}} \times -R = -10^{-\frac{3}{2} v_{q}}
\end{equation}

Since the op-amp has a huge input impedance, we can assume that the current flowing into $i^-$ is null:

\begin{equation}
\frac{v_i(s) - v^-}{R_i} + \frac{v_{hp}(s) - v^-}{R_g} + \frac{v_{lp}(s) - v^-}{R_g} + \frac{v_{lp}(s) - v^-}{R_g} + \frac{v_{bp}(s) \beta - v^-}{R_q} = i^- = 0
\end{equation}

The voltages at the inputs of the op-amp being equal, $v^-(s) = v^+(s) = 0$, hence:

\begin{equation}
\frac{v_i(s)}{R_i} + \frac{v_{hp}(s)}{R_g} + \frac{\alpha^2(s) v_{hp}(s)}{R_g} + \frac{v_{hp}(s) \alpha(s) \beta}{R_q} = 0
\end{equation}

The transfer function for the HP mode can be deduced from there:

\begin{eqnarray}
H_{hp}(s) &=& \frac{v_{hp}(s)}{v_i(s)} \\
 &=& \frac{-1 / R_i}{\frac{1}{R_g} + \frac{\alpha^2(s)}{R_g} + \frac{\alpha(s)\beta}{R_q}} \\
 &=& \frac{-R_g / R_i}{1 + \frac{R_g \alpha(s)\beta}{R_q} + \alpha^2(s)} \\
 &=& \frac{-G}{1 + \frac{R_g \alpha(s)\beta}{R_q} + \alpha^2(s)}
\end{eqnarray}

$G = \frac{R_g}{R_i}$ is the absolute value of the pass-band gain. For further simplifications, we assume $R_g = 2 R_q$.

The transfer function for the LP mode is:

\begin{eqnarray}
H_{lp}(s) &=& \frac{v_{lp}(s)}{v_i(s)} \\
 &=& \frac{v_{hp}(s)}{v_i(s)} \alpha^2(s) \\
 &=& \frac{-G}{\frac{1}{\alpha^2(s)} + \frac{2\beta}{\alpha(s)} + 1} \\
 &=& \frac{-G}{\frac{s^2}{{\left(\frac{1}{RC} 10 ^ {-\frac{3}{2} v_{cv}}\right)}^2} + 2 \frac{s}{{\left(\frac{1}{RC} 10 ^ {-\frac{3}{2} v_{cv}}\right)}} 10^{-\frac{3}{2} v_{q}} + 1}
\end{eqnarray}

By identification with the canonical form of a 2-nd order filter transfer function, this gives the following filter characteristics:

\begin{itemize}
\item Pass-band gain, $-G = -\frac{R_g}{R_i}$
\item Cutoff frequency, $f = \frac{1}{2 \pi R C} 10 ^ {-\frac{3}{2} v_{cv}}$
\item Q factor, $Q = \frac{1}{2} 10^{\frac{3}{2} v_{q}} $

\end{itemize}

Now, let us unleash the power of matplotlib and plot the filter response for several values of Q (rows), for the three modes (columns), and for 5 different cutoff settings (plots within a cell):

\begin{center}

\end{center}

\section{Practice}

\subsection{CV tuning}

Because it operates with small supplies ($\pm 5V$) and has its control signals living in the $[0, 5]V$ range, the Shruthi-1 uses the unusual $5V$ = $128$ midi notes scale, rather than the more common $1V$/octave scale -- which would be too narrow in this context. This implies a $2^{\frac{128}{12}} = 1625.5$ ratio between the lowest and highest cutoff frequencies reached by the filter. Using the relationship between cutoff frequency and $v_{cv}$, this implies that $v_{cv}$ swings by 2.141V between its smallest and highest value. The CV output by the Shruthi-1 has a 5V range, so the CV scaling circuit needs to have a $2.141 / 5 = 0.4282$ gain. This is more or less achieved by a $15k\Omega$ / $35k\Omega$ ratio, the $35k\Omega$ being obtained by a $33k\Omega$ resistor in series with a roughly centered $5k\Omega$ trimmer.

\subsection{1-pole filter on resonance CV}

The control signals generated by the Shruthi-1 are PWM modulated ; their 39kHz carrier needs to be removed by a low-pass filter. Cutoff signal conditioning is a serious matter, since the users want to calibrate the cutoff response to get tuned self-oscillation across several octaves. We cannot avoid dedicating PCB space to trimmers and a proper op-amp based cutoff CV scaling circuit.

When it comes to resonance, this is a different matter. The board space was limited and we did not have enough room to implement a proper active filter for smoothing the resonance CV. We went cheap with a passive $RC$ filter ($22k\Omega$, $68nF$, yielding a cutoff frequency of $106 Hz$), but there's a big caveat here! From the SSM2164 datasheet, the CV inputs of the SSM2164 are connected to a $4.5k\Omega$ / $500\Omega$ resistor divider. With the $RC$ filter in place adding some impedance at the input, the $v_{q}$ that the SSM2164 will ``see" is only $\rho = \frac{0.5 + 4.5}{0.5 + 4.5 + 22}$ of the CV output by the Shruthi-1 digital board. The new expression for $Q$ is thus $\frac{1}{2} 10^{\frac{3}{2} \rho v_{q}}$.

So much to save a pair of op-amps! We would have loved using a smaller $R$ to avoid adding to the input impedance of the SSM2164 control inputs, but then the capacitor would have been too large to fit on the board.

\subsection{Pushing self-oscillation}

Self-oscillation occurs when there is no feedback from the BP node to the input of the circuit. Unfortunately, this cannot occur with the circuit of section 1 since it is not possible to entirely mute the SSM2164 gain cell controlling resonance. With the Shruthi-1 Q CV set to a maximum value of $5V$, we get a Q of only $\frac{1}{2} 10^{\rho \frac{3}{2} \times 5} = 12.2$. Still not there! Self oscillation would happen if the signal fed back from the $BP$ node to the input of the filter was null ; but a small portion of it ``bleeds" through the feedback gain cell which is not entirely closed. We can cheat and compensate this bleed by always feeding back a small fraction of the $BP$ node to the input, through a $R_O$ resistor. In this case, the expression for $Q$ becomes:

$$Q = \frac{1}{2} \left(10^{-\frac{3}{2} \rho v_{q}} - \frac{R_Q}{R_O}\right)^{-1}$$

It is now possible to reach self-oscillation even if the feedback gain cell is bleeding a bit. The value of $R_O$ is chosen so that $Q$ can reach 0 before $v_{q}$ reaches $5V$. We observed a compensation of the bleed with values of $R_O$ lower than $680k\Omega$, and picked $R_O = 220k\Omega$ to be on the safe side, even if this means a less gentle ``landing" towards self oscillation.

\subsection{Soft clipping}

Once self-oscillation is reached, the bad surprise is that it crashes on the op-amp rails, yielding a very squelchy sound. Adding a pair of head-to-head Zeners across the BP integrator capacitor ensures that the self-oscillation signal will be soft-limited. We found that a Zener voltage of 4.7V gave the best results with TL07x op-amps (which crash at $\pm 3.6V$ when powered by $\pm 5V$).

\end{document}

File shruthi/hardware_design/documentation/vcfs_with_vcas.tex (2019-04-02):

\documentclass[a4paper,11pt]{article}
\usepackage[utf8]{inputenc}
\usepackage[T1]{fontenc}
\usepackage[english]{babel}
\usepackage{times}
\usepackage{graphicx}
\usepackage{tikz}
\usepackage{circuitikz}
\textwidth=6in
\textheight=9.0in
\headheight=0in
\headsep=0in
\oddsidemargin=0in
\evensidemargin=0in
\title{VCFs with VCAs}
\author{Emilie Gillet -- \tt emilie.o.gillet@gmail.com}
\date{}
\begin{document}

\maketitle

This document explains how a voltage-controlled amplifier (VCA) can be used to build a voltage-controlled filter (VCF).

\section{VCA cell}

A variety of VCA chips have been designed for musical applications. The CEM3381 and CEM3382 are current-in, current-out dual VCA chips with a linear or exponential response. The SSM2024 is a voltage-in, current-out quad CCA (current-controlled amplifier) with a linear response. All of them are discontinued. The CEM3381 and CEM3382 have been reincarnated as the PA381 and PA382 chips used in DSI's designs, but those chips are not sold to the general public.

In this document we will focus on the current-in, current-out VCA cell with a logarithmic response of the SSM2164. This popular and easily available chip from Analog Devices provides 4 of such VCA cells in a convenient DIP16 package. CoolAudio also sells its own version of this chip with the denomination V2164.

\begin{figure}
\begin{center}
\begin{circuitikz} \ctikzset{bipoles/not port/circle width=0}
 \draw
 (-3, 0.5) node[not port] (amp) {}
 (-6.5, 0.5) to[R, R=$R$, i=$i_{in}$] (amp.in)
 (amp.out) to[short, i=$i_{out}$] (-1.5, 0.5)
 (-7, 0.5) node[anchor=south] {$v_s$}
 (-3, -1) node[anchor=north] {$v_c$}
 (-3, -1) to (-3, 0.2)
;\end{circuitikz}
\end{center}
\caption{VCA cell symbol}
\label{fig:vca}
\end{figure}

Figure \ref{fig:vca} shows the symbol used for representing this cell. The input voltage $v_s$ is converted into the input current $i_{in}$ through the resistor $R$. $i_{out}$ is the output current, and $v_c$ is a control voltage modulating the gain. The behaviour of such a cell can be modelled by the following relationship:

$$i_{out} = i_{in} 10^{-\frac{3}{2} v_c} = \frac{v_s}{R} 10^{-\frac{3}{2} v_c}$$

On a decibel scale, the relationship between the control voltage and the gain is linear:

\begin{eqnarray*}
G_{db}(v_c) &=& 20\log_{10} \frac{i_{out}}{i_{in}} \\
&=& -30 v_c
\end{eqnarray*}

The response scale is thus $-30dB/V$.

It can be seen that contrary to what one would expect from a VCA module in a synthesizer, the gain is maximal for a null control voltage, and goes down exponentially as the control voltage increases. One might rather call this cell an ``attenuator" due to this reverse relationship!

\section{VCA-based LPF}

\subsection{1-pole LPF cell}

Let's model the circuit in figure \ref{fig:vcf} from left to right. The current at the input of the VCA is the sum of the input current, and the current fed back from the output:

\begin{figure}
\begin{center}
\begin{circuitikz} \ctikzset{bipoles/not port/circle width=0}
 \draw
 (0, 0) node[op amp] (opamp) {}
 (opamp.-) node[anchor=south] {$v'_-$}
 (opamp.+) to[short] (-1.5, -0.5)
 (opamp.out) to[short, -] (3, 0)
 (3, 0) node[anchor=south] {$v_o$}
 (-1.5, -0.5) to (-1.5, -1)
 (-1.5, -1) node[ground] {}
 (opamp.-) to[, -*] (-1.5, 0.5)
 (-1.5, 0.5) to (-1.5, 1.5)
 (-1.5, 1.5) to[C, C=$C$, -*] (2, 1.5)
 (2, 1.5) to[short] (2, 0)
 (2, 0) to[*-] (opamp.out)
 (2, 1.5) to (2, 3)
 (2, 3) to[R, R=$R$] (-4.5, 3)
 (-7, 0.5) to[R, R=$R$, i=$i_s$] (-5, 0.5)
 (-5, 0.5) to[short] (-4.5, 0.5)
 (-4.5, 3) to[i=$i_o$, -*] (-4.5, 0.5)
 (-3, 0.5) node[not port] (amp) {}
 (-4.5, 0.5) to[i=$i_{in}$] (amp.in)
 (amp.out) to[i=$i_{out}$] (-1.5, 0.5)
 (-7, 0.5) node[anchor=south] {$v_s$}
 (-3, -1) node[anchor=north] {$v_c$}
 (-3, -1) to (-3, 0.2)
;\end{circuitikz}
\end{center}
\caption{1-pole voltage-controlled low-pass filter based on a VCA cell}
\label{fig:vcf}
\end{figure}

\begin{eqnarray*}
i_{in}(p) &=& i_s(p) + i_o(p) \\
i_{in}(p) &=& \frac{1}{R}(v_s(p) + v_o(p))
\end{eqnarray*}

The op-amp is used as a current to voltage converter (or \emph{transimpedance amplifier}), and is inverting:

\begin{eqnarray*}
v_o(p) &=& -Z_{feedback}(p) i_-(p) \\
v_o(p) &=& -\frac{1}{Cp} i_{out}(p) \\
v_o(p) &=& -\frac{1}{Cp} 10^{-\frac{3}{2} v_c} i_{in}(p) \\
v_o(p) &=& -\frac{1}{Cp} 10^{-\frac{3}{2} v_c} \frac{1}{R}(v_o(p) + v_s(p)) \\
v_o(p) &=& \frac{-\frac{1}{RCp} 10^{-\frac{3}{2} v_c}v_s(p)}{\left(1 + \frac{1}{RCp} 10^{-\frac{3}{2} v_c} \right)}
\end{eqnarray*}

We can now compute the transfert function:

\begin{eqnarray*}
H(p) &=& \frac{v_o(p)}{v_s(p)} \\
H(p) &=& \frac{-1}{1 + RC 10^{\frac{3}{2} v_c} p} \\
\end{eqnarray*}

This is the transfer function of an (inverting) 1-pole low-pass filter, with a pole at the frequency zeroing the denominator:

\begin{eqnarray*}
1 + RC 10^{\frac{3}{2} v_c} 2 \pi f_c &=& 0 \\
f_c &=& \frac{-1}{2 \pi RC} 10^{-\frac{3}{2} v_c}
\end{eqnarray*}

A 4-pole filter can be created by simply chaining 4 such modules.

\subsection{Cutoff frequency scaling}

From the previous equation, it can be seen that $v_c$ controls the cutoff frequency with an exponential response, which is exactly the required behaviour! When $v_c$ is null, the cutoff frequency is that of the circuit $RC$ pair, and decreases with a $-30dB/V$ slope as $v_c$ increases. For example, if $v_c$ is equal to $2V$, the cutoff frequency will be $1/1000$ of the roll-off frequency of the $RC$ pair. Observe that this is the opposite of what one would expect from a VCF module: the cutoff frequency is high for low values of $v_c$ and reversely. To deal with that, the input control voltage has to be inverted, and shifted.

\begin{figure}
\begin{center}
\begin{circuitikz}
 \draw
 (0, 0) node[op amp] (opamp) {}
 (opamp.out) to[short] (2, 0)
 (2, 0) node[anchor=south] {$v_c$}
 (opamp.-) node[anchor=south] {$v'_-$}
 (opamp.+) to[short] (-1.5, -0.5)
 (-1.5, -0.5) to (-1.5, -1)
 (-1.5, -1) node[ground] {}
 (opamp.-) to[-*] (-1.5, 0.5)
 (-1.5, 0.5) to (-1.5, 2)
 (-1.5, 2) to[R, R=$R_2$] (1.5, 2)
 (1.5, 2) to[short, -*] (1.5, 0)
 (-1.5, 0.5) to (-1.5, 0.0)
 (-4, 0.0) to[R, R=$R_1$, -*] (-1.5, 0.0)
 (-4, 1) to[R, R=$R_1$, -*] (-1.5, 1)
 (-4, 1) node[anchor=east] {$v_{ee}$}
 (-4, 0) node[anchor=east] {$v_{CV}$}
;\end{circuitikz}
\end{center}
\caption{CV-scaling circuit for VCA-based LPF}
\label{fig:cv_scaler}
\end{figure}

This can be achieved by the simple op-amp summer/amplifier/inverter in figure \ref{fig:cv_scaler}.

$$v_c = -\frac{R_2}{R_1} {v_{ee}} - \frac{R_2}{R_1} v_{CV}$$

When $v_{CV}$ is null (low cutoff), the output is a positive value $-\frac{R_2}{R_1} {v_{ee}}$ yielding a high attenuation. When $v_{CV}$ is equal to $-v_{ee}$, $v_c$ is null, yielding the maximum cutoff value.

Let us figure what the values of the components should be for the Shruthi-1, in which the control voltage are in the $[0, 5]V$ range and the power supply is $\pm5V$.

First, we must decide on the filter $RC$. The value of $R$ is dictated by the SSM2164 datasheet, in which $30k\Omega$ resistors are always used on the inputs. Since we prefer values in the E12 series, let's stick to $R = 33k\Omega$. The value of $C$ must be such that the maximal cutoff frequency is outside of the human hearing range~-- let's pick $20kHz$. This yields $C = \frac{1}{2 \pi \times 20000 \times 33000} = 241pF$ close enough to the standard value of $220pF$.

If we want the cutoff to have a $5Hz$ to $20kHz$ range, $v_c$ must be such that an attenuation of $4000$ (or 72dB) is produced at the VCA when $v_{CV}$ is set to 0. Given the $30dB/V$ scale of the filter, this implies that $v_c = \frac{72}{30} = 2.4V$ to achieve this minimum cutoff frequency. If the VCA control voltage is produced by the op-amp circuit given above, this implies:

$$\frac{R_2}{R_1} = \frac{2.4}{5}$$

This ratio is close enough to what can be achieved with $R_1 = 100 k\Omega$ and $R_2 = 47 k\Omega$.

\subsection{Comparison with an OTA-based VCF}

The circuit described here has the following advantages over an OTA-based LPF:

\begin{itemize}
\item Better signal to noise ratio. OTAs require the input voltage to be scaled to a mV range.
\item Only 2 chips are required for a 4-pole VCF (the SSM2164 and a quad op-amp). The OTA version of the same filter requires 2 dual OTAs and a quad op-amp.
\item No need for an exponential current source, since the exponential conversion is built right into the chip. If high precision is required, this means no problem matching or thermally coupling transistors; and in any case, this reduces the part count.
\end{itemize}

A disputable advantage is that the VCA circuit yields less distortion. This is true, since OTAs, when not linearized, have a tanh shaping curve. But this non-linearity helps in giving character to the sound.

\section{Other circuits}

\subsection{1-pole High-pass filter}

\subsection{State variable filter}

\textit{To be continued}

\end{document}

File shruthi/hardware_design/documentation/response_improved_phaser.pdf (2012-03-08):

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

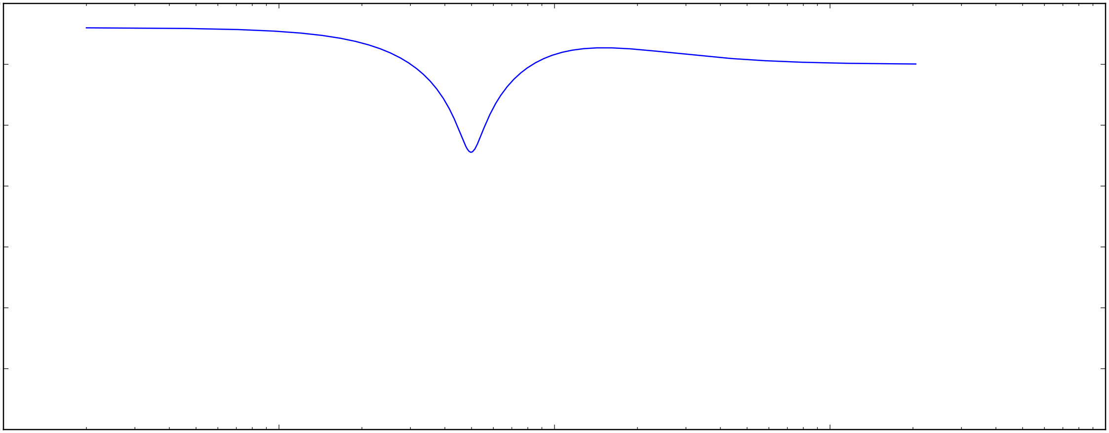
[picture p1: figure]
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

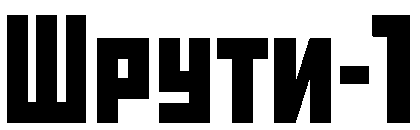
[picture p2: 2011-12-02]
shruthi/hardware_design/pcb/shruthi_russian.bmp

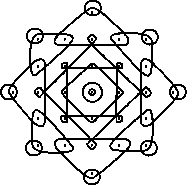
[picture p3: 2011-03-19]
dsp/hardware_design/pcb/rangoli.bmp

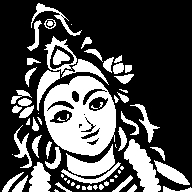
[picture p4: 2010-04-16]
shruthi/hardware_design/pcb/saraswati.bmp

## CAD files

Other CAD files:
shruthi/hardware_design/enclosures/shruthi_xt.dwg
shruthi/hardware_design/3d_model/shruthi-1_fancy_case.skp
shruthi/hardware_design/3d_model/shruthi-1_simple_case.skp

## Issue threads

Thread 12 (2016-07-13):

Enhancement: Add SSM2044 Filter Board Files

DatanoiseTV, 2016-07-13:
It seems like the SSM2044 Filter PCB and Schematic (http://mutable-instruments.net/shruthi1/build/ssm2044) was actually never published in the Git Repository.

Are you planing to add those?

Thanks
Datanoise

pichenettes, 2016-07-13:
Hi,

This is intentional. I removed the files from the git repository after
having discontinued this filter board. I really don't want to encourage
more people building it, especially since it doesn't do anything that
couldn't be done with the SMR4 filter board and mods.

Best,
Olivier

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

fralalonde, 2018-02-17:
Shouldnt you close this issue as "will not fix"?

pichenettes, 2018-02-17:
will not fix.

Closed 2018-02-17.

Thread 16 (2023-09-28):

SMR4-MK2-0.3-12V Why do not build ?

jojo-monk, 2023-09-28:
Hello,

I have this pcb, and I would like to know if there is a problem with this pcb, why it says "Do not build"?

pichenettes, 2023-09-28:
The split-supply design seemed like a good idea in terms of simplicity and cost/component count reduction, but the noise floor is higher than on the original design or the more recent versions (both employ dual supply).

Closed 2023-09-28.

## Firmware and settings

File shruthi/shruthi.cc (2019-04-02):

// Copyright 2009 Emilie Gillet.
//
// Author: Emilie Gillet (emilie.o.gillet@gmail.com)
//
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
#include "avrlib/devices/external_eeprom.h"
#include "avrlib/gpio.h"
#include "avrlib/boot.h"
#include "avrlib/serial.h"
#include "avrlib/timer.h"
#include "midi/midi.h"
#include "shruthi/audio_out.h"
#include "shruthi/midi_dispatcher.h"
#include "shruthi/part.h"
#include "shruthi/storage.h"
#include "shruthi/ui.h"

using namespace avrlib;
using namespace midi;
using namespace shruthi;

Serial<MidiPort, 31250, POLLED, POLLED> midi_io;
Serial<CvTxPort, 115200, DISABLED, POLLED> cv_io;
RingBuffer<SerialInput<MidiPort> > midi_buffer;

PwmOutput<kPinVcfCutoffOut> vcf_cutoff_out;
PwmOutput<kPinVcfResonanceOut> vcf_resonance_out;
PwmOutput<kPinVcaOut> vca_out;
PwmOutput<kPinCv1Out> cv_1_out;
PwmOutput<kPinCv2Out> cv_2_out;

MidiStreamParser<MidiDispatcher> midi_parser;

bool aux_uart_enabled = false;

ISR(TIMER2_OVF_vect) {
  static uint8_t clock_divider_midi = 0;
  static uint8_t clock_divider_ui = 0;

  // 40kHz: audio sample
  audio_out.EmitSample();

  // 10kHz: MIDI I/O
  --clock_divider_midi;
  if (!clock_divider_midi) {
    if (midi_io.readable()) {
      midi_buffer.NonBlockingWrite(midi_io.ImmediateRead());
    }
    if (midi_dispatcher.readable()) {
      if (midi_io.writable()) {
        midi_io.Overwrite(midi_dispatcher.ImmediateRead());
      }
    }
    clock_divider_midi = 4;
  }
  
  // 2.0kHz: UI polling
  --clock_divider_ui;
  if (!clock_divider_ui) {
    clock_divider_ui = 20;
    
    // The absolutely insane line of code that follows deserves a comment.
    // Ideally, we would have written: ui.Poll() to call the UI polling
    // routine. The problem is that the code in ui.Poll() thrash almost all
    // registers. gcc would have detected this and would have made sure that
    // (almost) all registers would have been pushed/popped in this ISR
    // prelude/postlude. As a result, 19 out 20 calls to this ISR, we
    // push/pop a dozen of registers for absolutely no useful purpose. This has
    // a cost of 40 CPU cycles per sample, and we don't want to spend that.
    // We want ui.Poll() [and all the necessary push/pop] to run in a different
    // context than this ISR - but still outside of the main loop.
    // Ideally, we would have loved to use user interrupts for that, but the AVR
    // doesn't have anything like this, so we enable a timer interrupt to jump
    // into its ISR ASAP...
    Timer<1>::Start();
  }
}

ISR(TIMER1_OVF_vect, ISR_NOBLOCK) {
  // ... and we disable the timer immediately!
  Timer<1>::Stop();
  ui.Poll();
}

void DSPFilterBoardWrite() {
  static uint8_t cv_io_round_robin = 0;
  
  uint8_t v;
  if (!aux_uart_enabled) {
    cv_io.Init();
    aux_uart_enabled = true;
  }
  
  // Shove two bytes to the serial output used for transmitting CVs to the
  // digital filter board.
  if (cv_io_round_robin == 0) {
    cv_io.Overwrite(0xff);
  } else if (cv_io_round_robin == 1) {
    cv_io.Overwrite(part.fx_control_byte());
  } else if (cv_io_round_robin == 2) {
    cv_io.Overwrite(part.sequencer_settings().seq_tempo);
  } else {
    v = part.voice().modulation_destination(
        MOD_DST_FILTER_RESONANCE + cv_io_round_robin - 3);
    if (v == 0xff) {
      v = 0xfe;
    }
    cv_io.Overwrite(v);
  }
  v = part.voice().modulation_destination(
      MOD_DST_FILTER_CUTOFF + (cv_io_round_robin & 1));
  if (v == 0xff) {
    v = 0xfe;
  }
  cv_io.Overwrite(v);
  cv_io_round_robin = (cv_io_round_robin + 1);
  if (cv_io_round_robin == 6) {
    cv_io_round_robin = 0;
  }
}

void FillAudioBuffer() {
  if (!audio_out.writable_block()) {
    return;
  }

  part.ProcessBlock();
  uint8_t filter_board = part.system_settings().expansion_filter_board;
  uint8_t resonance = part.voice().resonance();
  uint8_t gain = part.voice().vca();
  uint8_t cv_1 = part.voice().cv_1();
  uint8_t cv_2 = part.voice().cv_2();
  vcf_cutoff_out.Write(part.voice().cutoff());

  if (filter_board == FILTER_BOARD_DSP) {
    DSPFilterBoardWrite();
  } else if (filter_board == FILTER_BOARD_PVK) {
    // Mirror unprocessed Cutoff/Resonance values for Shruthi-XP.
    if (part.system_settings().programmer == PROGRAMMER_FCD) {
      uint8_t adjusted_cutoff = part.voice().cutoff();
      if (adjusted_cutoff > 24) {
        adjusted_cutoff -= 24;
      } else {
        adjusted_cutoff = 0;
      }
      cv_1 = resonance;
      cv_2 = adjusted_cutoff;
    }
    // Apply a knee to the resonance curve.
    resonance = (resonance >> 1) + (resonance < 128 ? resonance : 128);
    if (resonance >= 252) {
      resonance = 255;
    }
  } else if (filter_board == FILTER_BOARD_DLY) {
    if (aux_uart_enabled) {
      cv_io.Disable();
      aux_uart_enabled = false;
    }
    uint8_t level = part.patch().filter_1_mode_;
    uint8_t tilt = part.patch().filter_2_mode_ << 1;
    uint8_t gain;
    gain = U8U8Mul(level, tilt < 16 ? tilt : 16);
    cv_2 = pgm_read_byte(wav_res_ssm2164_linearization + (gain >> 2));
    gain = U8U8Mul(level, tilt > 16 ? (30 - tilt) : 16);
    cv_1 = pgm_read_byte(wav_res_ssm2164_linearization + (gain >> 2));
    // Apply a knee to the resonance curve.
    resonance = ~resonance;
    resonance = U8U8MulShift8(resonance, resonance);
    resonance = U8U8MulShift8(~resonance, 160) + 48;
  } else if (filter_board == FILTER_BOARD_4PM) {
    // Mirror unprocessed Cutoff/Resonance values for Shruthi-XP.
    if (part.system_settings().programmer == PROGRAMMER_FCD) {
      cv_1 = resonance;
      cv_2 = part.voice().cutoff();
    }
    // If the resonance overdrive mode is not selected, half the scale of
    // the resonance setting. Resonance overdrive needs a very strong control
    // current on the OTA to kick in.
    if ((part.patch().filter_2_mode_ & 1) == 0) {
      resonance = U8U8MulShift8(resonance, 92);
    } else {
      gain = ~gain;
      gain = U8U8MulShift8(gain, gain);
      gain = ~gain;
    }
  }
  vcf_resonance_out.Write(resonance);
  vca_out.Write(gain);
  cv_1_out.Write(cv_1);
  cv_2_out.Write(cv_2);
  
  if (audio_out.num_glitches()) {
    audio_out.ResetGlitchCounter();
    display.set_status('!');
  }
}

void ProcessMidi() {
  while (midi_buffer.readable()) {
    midi_parser.PushByte(midi_buffer.ImmediateRead());
  }
}

void Init() {
  sei();
  audio_out.Init();
  midi_io.Init();
  
  // Initialize all the PWM outputs to 39kHz, phase correct mode.
  Timer<0>::set_prescaler(1);
  Timer<0>::set_mode(TIMER_PWM_PHASE_CORRECT);
  Timer<1>::set_prescaler(1);
  Timer<1>::set_mode(TIMER_PWM_PHASE_CORRECT);
  Timer<2>::set_prescaler(1);
  Timer<2>::set_mode(TIMER_PWM_PHASE_CORRECT);
  
  vcf_cutoff_out.Init();
  vcf_resonance_out.Init();
  vca_out.Init();
  cv_1_out.Init();
  cv_2_out.Init();

  ui.Init();
  Storage::Init();
  part.Init();
  
  ui.ShowSplash();
  Timer<2>::Start();
}

int main(void) {
  Init();
  while (1) {
    FillAudioBuffer();
    ProcessMidi();
    ui.DoEvents();
  }
}

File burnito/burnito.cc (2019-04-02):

// Copyright 2010 Emilie Gillet.
//
// Author: Emilie Gillet (emilie.o.gillet@gmail.com)
//
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
#include "avrlib/devices/buffered_display.h"
#include "avrlib/devices/external_eeprom.h"
#include "avrlib/devices/hd44780_lcd.h"
#include "avrlib/devices/shift_register.h"
#include "avrlib/gpio.h"
#include "avrlib/boot.h"
#include "avrlib/parallel_io.h"
#include "avrlib/time.h"
#include "avrlib/string.h"

#include "burnito/resources.h"

using namespace avrlib;
using namespace avrlib;

static const uint16_t kBankSize = 8192;
static const uint16_t kMaxNumBanks = 7;
static const uint8_t kBlockSize = 64;

typedef Hd44780Lcd<
    Gpio<PortC, 2>,
    Gpio<PortC, 3>,
    ParallelPort<PortC, PARALLEL_NIBBLE_HIGH> > Lcd;

ShiftRegisterOutput<
    Gpio<PortD, 2>,
    Gpio<PortB, 7>,
    Gpio<PortB, 5>, 8, MSB_FIRST> status_leds;

Lcd lcd;
BufferedDisplay<Lcd> display;
ExternalEeprom<kMaxNumBanks * kBankSize> external_eeprom;


static uint8_t cpt;
TIMER_2_TICK {
  cpt = (cpt + 1) & 0x0f;
  if (cpt == 0) {
    lcd.Tick();
  }
}

TIMER_0_TICK {
  TickSystemClock();
}

static uint8_t num_banks;

static const uint16_t kTotalSize = BLOB_RES_EEPROM_CONTENT_SIZE + \
    BLOB_RES_EEPROM_CONTENT_TAIL_SIZE;

void DetectEepromSize() {
  external_eeprom.Init();
  uint16_t address = kMaxNumBanks * kBankSize - 2;
  uint16_t data;
  // Write the sequence 0xfadN at the end of each bank, where N is the
  // bank number.
  for (uint8_t i = kMaxNumBanks; i > 0; --i) {
    data = 0xfad0 + i;
    external_eeprom.Write(address, (uint8_t*)&data, 2);
    address -= kBankSize;
  }
  // Try to read back this data to figure out the actual number of banks.
  address = kMaxNumBanks * kBankSize - 2;
  num_banks = kMaxNumBanks;
  while (num_banks > 0) {
    external_eeprom.Read(address, 2, (uint8_t*)&data);
    if (data == 0xfad0 + num_banks) {
      break;
    }
    --num_banks;
    address -= kBankSize;
  }
  
  char line_buffer[16];
  line_buffer[0] = '\0';
  strcpy(line_buffer, "Size: ");
  UnsafeItoa(num_banks * (kBankSize / 1024 * 8), 5, line_buffer + 6);
  strcat(line_buffer, "kb");
  display.Print(0, line_buffer);
}

uint8_t buffer[kBlockSize];
uint8_t buffer2[kBlockSize];

uint8_t Copy() {
  display.Print(1, "Copying...      ");
  
  uint16_t address = 0;
  uint8_t progress = 0;
  for (uint8_t i = 0; i < num_banks; ++i) {
    for (uint16_t j = 0; j < kBankSize; j += kBlockSize) {
      display.Tick();
      memcpy_P(
          buffer,
          burnito::blob_res_eeprom_content + address,
          kBlockSize);
      if (external_eeprom.Write(address, buffer, kBlockSize) != kBlockSize) {
        return 0;
      }
      address += kBlockSize;
      status_leds.Write((1 << (progress + 1)) - 1);
      progress = (progress + 1) & 7;
      if (address == kTotalSize) {
        break;
      }
    }
  }
  return 1;
}

uint8_t Verify() {
  display.Print(1, "Verifying...    ");
  
  uint16_t address = 0;
  uint8_t progress = 0;
  for (uint8_t i = 0; i < num_banks; ++i) {
    for (uint16_t j = 0; j < kBankSize; j += kBlockSize) {
      display.Tick();
      memcpy_P(
          buffer,
          burnito::blob_res_eeprom_content + address,
          kBlockSize);
      if (external_eeprom.Read(address, kBlockSize, buffer2) != kBlockSize) {
        return 0;
      }
      if (memcmp(buffer2, buffer, kBlockSize)) {
        return 0;
      }
      address += kBlockSize;
      status_leds.Write((1 << (progress + 1)) - 1);
      progress = (progress + 1) & 7;
      if (address == kTotalSize) {
        break;
      }
    }
  }
  return 1;
}

int main(void) {
  Boot(true);
  lcd.Init();
  status_leds.Init();
  Timer<2>::set_prescaler(1);
  Timer<2>::set_mode(TIMER_PWM_PHASE_CORRECT);
  Timer<2>::Start();
  display.Init();
  DetectEepromSize();
  if (!Copy()) {
    display.Print(1, "Copy error!     ");
    status_leds.Write(0x55);
  } else {
    if (!Verify()) {
      display.Print(1, "Read error!     ");
      status_leds.Write(0x55);
    } else {
      display.Print(1, "EEPROM ok!      ");
      status_leds.Write(0xff);
    }
  }
  while (1) {
    display.Tick();
    Delay(1);
  }
}

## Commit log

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2010-03-04 Layout for analog board
    [Shruthi-Analog-v01.brd, Shruthi-Analog-v01.sch, Shruthi-Digital-v01.brd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]
2010-03-07 Missing files
    [Shruthi-Analog-v01.brd]
2010-03-08 More work on hal and bootloader
    [Shruthi-Digital-v01.brd, Shruthi-Digital-v01.sch]
2010-03-08 Logic board: removed LEDs, added one switch
    [Shruthi-Digital-v01.brd, Shruthi-Digital-v01.sch]
2010-03-09 Prepared work on UI simplified simplified UI (8 LEDs) + PCB tweaks
    [Shruthi-Analog-v01.brd, Shruthi-Analog-v01.sch, Shruthi-Digital-v01.brd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]
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2010-03-09 Port of the Shruti code to the Shruthi platform
    [Shruthi-Digital-v01.GBL, Shruthi-Digital-v01.GBO, Shruthi-Digital-v01.GBS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]
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2010-03-13 - Reworked bootloader to use multiplexed switches - Added input shift register (74hc165) template - Added switch array class for higher level access to shifted switches (includes debouncing)
    [Shruthi-Digital-v01.brd, Shruthi-Digital-v01.sch, Shruthi-Digital-v01_165.brd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]
2010-03-14 Fixed formatting, added reset to init / send by SysEx commands
    [Shruthi-Analog-v01.sch, Shruthi-Digital-v01.brd, Shruthi-Digital-v01.sch]
2010-03-15 Added missing file (midi out filter)
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2010-03-16 Oscillators refactoring
    [Shruthi-Analog-v01.brd, Shruthi-Analog-v01.sch]
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2010-03-22 - PWM is now implemented with two dephased sawtooth waves, for a cleaner sound. - The blit oscillator has been removed. - Rotary encoder is now read from an interrupt, for a better handling of fast m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
    [Shruthi-Analog-v01.brd, Shruthi-Analog-v01.sch, Shruthi-Digital-v01.brd]
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2010-04-02 Fixed i2c pins
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2010-04-04 Fixes after proto build
    [Shruthi-Analog-v01.brd, Shruthi-Digital-v01.brd, Shruthi-Digital-v01.sch]
2010-04-05 Fixed 2 LFO bugs ; increased encoder readout frequency
    [lfo.h, shruthi.cc]
2010-04-05 Changed position of GND/5V in stacking ; renamed PrettyPrinter to OutputStream
    [Shruthi-Analog-v01.brd, Shruthi-Analog-v01.sch, Shruthi-Analog-v02.brd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]
2010-04-06 More experiments with resonance problem
    [Shruthi-Analog-v02.brd, Shruthi-Analog-v02.sch, Shruthi-Digital-v02.brd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]
2010-04-07 Towards lower noise on the PWM outputs...
    [Shruthi-Analog-v02.brd, Shruthi-Digital-v02.brd, Shruthi-Digital-v02.sch]
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2010-04-10 Fixed endless recursion in arpeggiator code. Fixed the way navigation changes with the rotary encoder are saved the 'last visited page' variable
2010-04-13 Looping envelope bug. Fixed transient leaking into ground in analog board
    [Shruthi-Analog-v02.brd, Shruthi-Analog-v02.sch, Shruthi-Digital-v02.brd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]
2010-04-13 Added analog filter type to analog board name
    [Shruthi-Analog-CEM3379-v02.brd, Shruthi-Analog-CEM3379-v02.sch]
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2010-04-21 New sequencer and LFO options + pad oscillator
    [Shruthi-Analog-SMR4-v01.brd, Shruthi-Analog-SMR4-v01.sch]
2010-04-25 - fixed enveloppe plopping bug - fixed dropped MIDI bytes crash - added detuned sawtooth oscillator - PCB and schematics tweaks
    [Shruthi-Analog-CEM3379-v02.brd, Shruthi-Analog-CEM3379-v02.sch, Shruthi-Analog-SMR4-v01.brd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]
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2010-05-01 PCB tweaks, new default patch, fixed plop after key release bug, and rework filter design file
    [Shruthi-Analog-CEM3379-v02.brd, Shruthi-Analog-CEM3379-v02.sch, Shruthi-Analog-SMR4-v01.brd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]
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2010-05-02 Fixed examples, some PCB tweaks
    [Shruthi-Analog-SMR4-v01.brd, Shruthi-Analog-SMR4-v01.sch]
2010-05-03 Work in progress: unification of load/save and SysEx rx/tx code for patches and sequences
    [Shruthi-Analog-CEM3379-v02.brd, Shruthi-Analog-CEM3379-v02.sch, Shruthi-Analog-SMR4-v01.brd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]
2010-05-04 Improved swing algorithm to use adjustable groove templates (swing, shuffle, humanize...). Refactored UI logic to have two sets of pages, one for the patch and one for the sequencer. Removed velocity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
    [Shruthi-Digital-v02.brd, Shruthi-Digital-v02.sch]
2010-05-05 Improved SysEx reception, fixed bug. Patch and Sequence reception is now working
    [Shruthi-Digital-v02.brd, Shruthi-Digital-v02.sch]
2010-05-10 Added transient generator, sharing some resources with the sub-oscillator
    [Shruthi-Analog-CEM3379-v02.brd, Shruthi-Analog-CEM3379-v02.sch, Shruthi-Analog-SMR4-v01.brd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]
2010-05-12 Fuzz mixing mode is stable, but we're short on CPU usage
    [resources.cc, shruthi.cc, shruthi.h]
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2010-05-13 Tiny fix in CC handling. CEM3379 compatibility board now uses the same power supply circuit as the LM13700 board
    [Shruthi-Analog-CEM3379-v02.brd, Shruthi-Analog-CEM3379-v02.sch]
2010-05-14 Power supply revisions (thanks Todd...) ; moved the pots down on the control panel board
    [Shruthi-Analog-CEM3379-v02.brd, Shruthi-Analog-CEM3379-v02.sch, Shruthi-Analog-SMR4-v01.brd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]
2010-05-14 Fixed bug introduced by empty block optimization
    [Shruthi-Analog-CEM3379-v02.brd, Shruthi-Analog-CEM3379-v02.sch, Shruthi-Analog-SMR4-v01.brd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]
2010-05-17 - Parameter meta definitions are now stored outside of the editor code - CCificatino - Assignable CCs are now shown as modulation sources - Cycle start/duration is now assignable in performance page
    [Shruthi-Analog-CEM3379-v02.brd, Shruthi-Analog-SMR4-v01.brd]
2010-05-19 Added new 'one shot' wavetables, revised PCBs with TL074 instead of TL084, and fixed MIDI utility so that it does not create comments tracks by default
    [Shruthi-Analog-CEM3379-v02.brd, Shruthi-Analog-CEM3379-v02.sch, Shruthi-Analog-SMR4-v01.brd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]
2010-05-20 Added new wavetables and crushed oscillator
    [resources.cc, resources.h]
2010-05-25 More wavetables, fix for ATMega1284p, removed Audio rate update of voice controller, misc. style fixes
    [bootloader.cc, resources.cc, resources.h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]
2010-05-28 Reverted back to the 644p with 5 wavetables. Fixed bug with very low notes
    [resources.cc, resources.h]
2010-05-29 Fixed the order of hard buttons (The first proto board had the buttons wired in the wrong order). PCB fix (text position, swapped two incorrect resistor values)
    [Shruthi-Analog-CEM3379-v02.brd, Shruthi-Analog-SMR4-v01.brd, Shruthi-Analog-SMR4-v01.sch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]
2010-05-30 - Fixed a bug in the handling of the keyboard which caused a "Shift key is raised" event whenever a "Shift + other key" combo was released. - Added audio signal as a modulation source. - Added fine p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
    [Shruthi-Analog-SMR4-v01.brd, Shruthi-Analog-SMR4-v01.sch]
2010-05-31 Rearranged board to make more room for the neutrik connectors; and to have more space between pots and LCD
    [Shruthi-Digital-v02.brd, Shruthi-Digital-v02.sch, Shruthi-Digital-v03.brd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]
2010-05-31 Reworked MIDI output code to provide an option to send all edit commands as NRPN CCs. Implementation of Poly-chaining
    [resources.cc, resources.h, shruthi.cc]
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2010-06-01 Moved DC connector on PCBs ; removed dead code ; more robust NRPN handling ; the LCD display now reflects parameter changes received by NRPN
    [Shruthi-Analog-CEM3379-v02.brd, Shruthi-Analog-CEM3379-v03.brd, Shruthi-Analog-CEM3379-v03.sch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]
2010-06-06 - Rewrote bootloader (removed STK500 mode) - Test note is now a C3 instead of a C2 - Brought back some of the wavetables, with a 128-cycle size instead of 256 - For better latency, MIDI output is don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
    [Shruthi-Analog-SMR4-v02.brd, Shruthi-Analog-SMR4-v02.sch]
2010-06-07 Prevent crashes when the eeprom chip is missing
    [resources.cc]
2010-06-07 Do not override splashscreen at startup. Removed useless write in shift register code
    [Shruthi-Digital-v03.brd, Shruthi-Digital-v03.sch]
2010-06-08 Fix patch checking
    [Shruthi-Digital-v03.brd, Shruthi-Digital-v03.sch]
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2010-06-19 Added optional knob value snapping, MIDI split, NRPN hardening, and a fix in external clock synchronization code
    [Shruthi-Analog-SSM2044-v01.brd, Shruthi-Analog-SSM2044-v01.sch]
2010-06-19 Fixes to SSM2044 board
    [Shruthi-Analog-SSM2044-v01.brd, Shruthi-Analog-SSM2044-v01.sch]
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2010-06-23 Oops, board variant names swapped
    [Shruthi-Digital-v04a.brd, Shruthi-Digital-v04a.sch, Shruthi-Digital-v04b.brd]
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2010-06-24 Validated pull-up fix. Added extra holes for fitting Reichelt MIDI connectors
    [Shruthi-Digital-v04.brd, Shruthi-Digital-v04.sch]
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2010-06-27 Applied second-order dithering to wavetables for basic waveforms
    [Shruthi-Digital-v04.brd]
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2010-07-09 Added documentation for the SMR-4 filter board. Changed the version number and splash screen text
    [Shruthi-Analog-SMR4-v02.brd, Shruthi-Analog-SMR4-v03.brd, Shruthi-Analog-SMR4-v03.sch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]
2010-07-12 Support for rev 0.4/0.5 digital boards ; cosmetic change to v0.4 board
    [Shruthi-Digital-v04.brd]
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2010-07-14 Updated filter board with op-amp integrator, area for resonance feedback customization
    [Shruthi-Analog-SMR4-v03.brd, Shruthi-Analog-SMR4-v03.sch, Shruthi-Analog-SMR4-v04.brd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]
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2010-07-15 Added dev board with power supply, input and output stages, connectors
    [Shruthi-Analog-dev.brd, Shruthi-Analog-dev.sch]
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2010-07-18 - Arpeggiator patterns are now numbered from 1 to 15 instead of 0 to 14. - "Flow" has been renamed "Warp" - SysEx are now output through the correct UART (rev4/rev2 hardware) - Fixed a bug in NRPN pa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
    [resources.cc, resources.h, shruthi.h]
2010-07-18 Fixed bug in split mode. Patch index can now be up to 3 digits large (for future memory extensions)
    [bootloader.cc]
2010-07-22 Docs fixes
    [Shruthi-Analog-template-v01.brd]
2010-07-29 Added pre-attack envelope smoothing, reworked the sub-oscillator to make them more aggressive (disabled anti-aliasing and increased sample rate)
    [resources.cc, resources.h]
2010-07-29 Trick to avoid switch in subosc code
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2010-08-14 Redesign of the SSM2044 board
    [Shruthi-Analog-SSM2044-v01.brd, Shruthi-Analog-SSM2044-v01.sch]
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2010-08-16 Revised layout of SSM2044 board: high-Z summing nodes are no longer spread over dozens of cm, lonely TL074 op-amp cell is correctly grounded. Placeholder for logo
    [Shruthi-Analog-SSM2044-v01.brd, Shruthi-Analog-SSM2044-v01.sch]
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2010-08-22 Fixed DC offset filter
    [Shruthi-Analog-SSM2044-v01.brd, Shruthi-Analog-SSM2044-v01.sch]
2010-08-22 Fixed type, template with 2x cases for Ponoko
    [shruthi-1_simple_case.skp]
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2010-09-07 Fixed NRPN of death
    [Shruthi-Analog-SSM2044-v01.brd, Shruthi-Analog-SSM2044-v01.sch]
2010-09-11 PCB revisions: CEM3379 filter board now has the same PSU layout as the other boards. SSM2044 board has more space for the HPF capacitors, so polystyrene caps can be used there too
    [Shruthi-Analog-CEM3379-v04.brd, Shruthi-Analog-CEM3379-v04.sch, Shruthi-Analog-CEM3379-v05.brd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]
2010-09-11 Added markers on board to indicate where to shunt the pot connector
    [Shruthi-Analog-CEM3379-v05.brd, Shruthi-Analog-SMR4-v05.brd, Shruthi-Analog-SMR4-v05.sch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]
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2010-09-23 Minor fixes on SSM2044 board: more space around filter capacitors
    [Shruthi-Analog-SSM2044-v02.brd, Shruthi-Analog-SSM2044-v02.sch, Shruthi-Digital-v05.brd]
2010-10-01 Fixed bug in storage size. No effect on current firmware since the patch and seq memory both have 80 slots
    [Shruthi-Analog-CEM3379-v05.brd, Shruthi-Analog-SMR4-v06.brd, Shruthi-Analog-SMR4-v06.sch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]
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2010-10-16 Adding commented code for low-fi oscillator version + PCB revisions
    [Shruthi-Analog-SMR4-v06.brd, Shruthi-Analog-SMR4-v06.sch, Shruthi-Digital-v05.brd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]
2010-10-24 Revised board layout ; added expansion connectors on Digital board. Added cutoff CV inputs on analog boards. Removed middle spacers
    [Shruthi-Analog-SMR4-v06.brd, Shruthi-Analog-SMR4-v06.sch, Shruthi-Digital-v06.brd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]
2010-10-26 Improved encoder accuracy, changed 'load' caption to 'browse'
    [Shruthi-Analog-CEM3379-v05.brd, Shruthi-Analog-CEM3379-v05.sch, Shruthi-Analog-SMR4-v06.brd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]
2010-10-26 Encoder accuracy fix
    [Shruthi-Analog-SMR4-v06.brd]
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2010-10-30 Fixed bug in pot scanning comparison
    [shruthi.cc]
2010-11-05 Do not reset LED pattern in case of unexpected byte
    [bootloader.cc]
2010-11-05 Correction on digital board
    [Shruthi-Digital-v06.brd]
2010-11-14 Fixed AVRdude options for fuses ; PCB upgrades
    [Shruthi-Analog-CEM3379-v05.brd, Shruthi-Analog-CEM3379-v05.sch, Shruthi-Analog-SMR4-v06.brd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]
2010-11-14 Added missing board files
    [Shruthi-Analog-SSM2044-v02.sch, Shruthi-Analog-template-v02.brd]
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2010-11-23 Added new filter board design (WIP) for Roland IR3109 chip
    [Shruthi-Analog-IR3109-v01.brd, Shruthi-Analog-IR3109-v01.sch]
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2010-11-25 IR3109 board, fixed positioning of bypass caps
    [Shruthi-Analog-IR3109-v01.brd]
2011-02-05 Fixed bug in autosize detection, now works for larger eeproms
    [shruthi.h]
2011-02-05 Handling of volume CC, breakdown of modulation matrix into blocks, 'intelligent' digital silencing of oscillators
    [shruthi.cc]
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2011-02-12 Simplified glitch counter code
    [shruthi.cc]
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2011-02-15 First commit of the Burnito firmware
    [burnito.cc, resources.cc, resources.h]
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2011-02-20 Updated burnito to write large eeproms (464kb)
    [burnito.cc, resources.cc, resources.h]
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2011-02-23 Work in progress for computing the CV scaling circuit for 2164-based filters
    [expo_converter.sch, linear_current_source.sch, vca_control_knee.sch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]
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2011-02-26 Fixed undo buffer bug
    [storage.h]
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2011-03-14 IR3109 board fixes
    [Shruthi-Analog-IR3109-v01.brd, Shruthi-Analog-IR3109-v01.sch]
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2011-03-21 Reworked analysis document and simulation script with SSM2164 output fed into a virtual ground
    [Shruthi-Analog-SVF-v01c.brd, Shruthi-Analog-SVF-v01c.sch]
2011-03-21 VCA output current fed straight into final op-amp
    [Shruthi-Analog-SVF-v01c.brd, Shruthi-Analog-SVF-v01c.sch]
2011-03-21 Moving to the save page no longer reverts the edit buffer
    [editor.h]
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2011-03-24 Added DC blocking caps and pusher resistor to SVF board
    [Shruthi-Analog-SVF-v01c.brd, Shruthi-Analog-SVF-v01c.sch]
2011-03-24 SVF PCB fixes
    [Shruthi-Analog-SVF-v01c.brd]
2011-03-28 Reworked brickwall filters on digital VCF board
    [Shruthi-Analog-BlipToo12-v01.brd, Shruthi-Analog-BlipToo12-v01.sch]
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2011-03-28 Reworked DSP filter board. Almost ready
    [Shruthi-Analog-BlipToo12-v01.brd, Shruthi-Analog-BlipToo12-v01.sch, Shruthi-Analog-SVF-v01b.brd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]
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2011-03-31 Added oscillators and patch matrix, started routing of OTP board
    [Shruthi-OneTrickPony-v01.brd, Shruthi-OneTrickPony-v01.sch]
2011-03-31 Won't work with TL082p obviously
    [Shruthi-OneTrickPony-v01.brd, Shruthi-OneTrickPony-v01.sch]
2011-03-31 Fixed hatched ground planes
    [Shruthi-Analog-SVF-v01c.brd, Shruthi-DSP-v01.brd]
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2011-04-12 Reworking the SVF board. Added resitor for SSM2164 mode control - won't be needed probably
    [Shruthi-Analog-SVF-v01.brd, Shruthi-Analog-SVF-v01.sch, Shruthi-DSP-v01.brd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]
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2011-04-19 Oops, added missing bypass caps
    [Shruthi-DSP-v01.brd, Shruthi-DSP-v01.sch, Shruthi-DSP-v02.brd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]
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2011-04-27 Minor fixes on the sidekick board
    [Sidekick-v02.brd, Sidekick-v02.sch]
2011-04-30 Fixed pot polarity
    [Sidekick-v02.brd, Sidekick-v02.sch]
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2011-04-30 Fixed text on DSP board
    [Shruthi-DSP-v02.brd]
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2011-05-04 Minimal program for the DSP filter board - samples the input and the VCA signal, do the multiplication and write to the output.
    [Shruthi-Analog-SMR4-mkII-v01.brd, Shruthi-DSP-v02.brd, Shruthi-DSP-v02.sch]
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2011-05-08 Fixed Program Change bug
    [editor.h]
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2011-05-13 DSP board transmission protocol fix
    [dsp.cc, shruthi.cc]
2011-05-15 New filter code ; fixed some bugs
    [dsp.cc, resources.cc, resources.h]
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2011-05-27 Fixed invalid string id
    [resources.cc, resources.h]
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2011-05-29 612 PCB routed. will rest for a while
    [Shruthi-612-v01.brd, Shruthi-612-v01.sch]
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2011-06-03 Fixes to SMR4 mkII board
    [Shruthi-Analog-SMR4-mkII-v01.brd, Shruthi-Analog-SMR4-mkII-v01.sch]
2011-06-03 Fixed typo in ADC alignment function
    [dsp.cc]
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2011-07-14 Fixed Shruthi-1 build to use latest avrlib
    [bootloader.cc, hardware_config.h, storage.h]
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2011-07-26 Fixes to DSP board
    [Shruthi-DSP-v03.brd, Shruthi-DSP-v03.sch]
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2011-09-06 Fixed sample rate bug
    [resources.cc, resources.h, shruthi.h]
2011-09-17 Vowel oscillator code simplification
    [resources.cc, resources.h]
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2011-09-18 Factored out bits of pitch computation which are common to both oscillators
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2011-11-13 Fixed page scrolling of secondary filter page
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2011-11-14 Reworked pitch table
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2011-11-23 Fixed PWM blep
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2011-12-05 Fixed bug with CC control of Polivoks filter routing
2011-12-05 Fixed bug with CC control of Polivoks filter routing - simpler solution
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2011-12-07 SMR4 mkII: no longer using the LM13700 darlington buffer
    [Shruthi-Analog-SMR4-mkII-v01.brd, Shruthi-Analog-SMR4-mkII-v01.sch]
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2012-02-29 Fixed memory corruption bug
    [shruthi.cc]
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2012-03-08 Fixed computation of routing byte for 4-pole filter board
    [shruthi.cc]
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2012-03-08 Fixed resonance
    [Shruthi-Analog-PoleMixing-v02.brd, Shruthi-Analog-PoleMixing-v02.sch]
2012-03-12 Re-specialization of PWM oscillator
    [oscillator.cc]
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2012-03-19 Fixed Polivoks board cutoff range
2012-03-31 Fixed LED pattern
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2012-04-13 Added missing files
    [Shruthi-Analog-PoleMixing-v02.brd, Shruthi-Analog-PoleMixing-v02.sch, Shruthi-Digital-v07pm.brd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]
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2012-05-31 Inclusion of flip's programmer parameter page
    [editor.h, shruthi.cc]
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2012-07-07 Reworked delay circuit
    [Shruthi-Analog-LP2Delay-v01.brd, Shruthi-Analog-LP2Delay-v01.sch, Shruthi-Analog-LP2Delay-v02.brd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]
2012-07-09 Envelope fix
    [Shruthi-Analog-LP2Delay-v02.brd, Shruthi-Analog-LP2Delay-v02.sch]
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2012-08-18 Fixed retriggering velocity
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2012-08-29 Added missing entry in pitch table
    [Shruthi-Analog-LP2Delay-v02.brd, Shruthi-Analog-LP2Delay-v02.sch]
2012-09-27 Reworked PCB logos
    [Shruthi-Analog-SMR4-mkII-v02.brd, Shruthi-Analog-SMR4-mkII-v02.sch, Shruthi-Digital-v07jp.brd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]
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2013-02-22 Prevent lockup of RNG at boot
    [oscillator.cc]
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2013-07-16 Fixed long note triggering
    [part.cc, ui.cc]
2013-07-19 Fixed blank ticks check
    [part.cc]
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2013-07-24 Jam mode + snap with programmer
    [editor.h, resources.cc, resources.h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]
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2013-08-30 SVF v0.3 VCA fix
    [Shruthi-Analog-SVF-v03.brd, Shruthi-Analog-SVF-v03.sch]
2013-10-02 Fixed refresh loop bug
    [editor.h, ui.cc]
2013-11-14 Corrected version number in resources from 0.98 -> 1.0
    [resources.cc]
2013-11-14 Fixed WAV_RES_VERSION index to match XT refactoring
    [resources.h]
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2013-12-11 Reworked XT PCB
    [Shruthi-Digital-XT-v03.brd, Shruthi-Digital-XT-v03.sch]
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2013-12-28 Fixed cursor blink; snap mode on preset page; groove amount; init patch
    [part.cc, ui.cc]
2014-01-10 Oscillator fn table is const
    [oscillator.cc]
2014-01-10 Oscillator table is const
    [oscillator.cc]
2014-02-03 Fix for all notes off
    [part.cc]
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2020-03-25 Fixed file names, name on board
    [Shruthi-Analog-SMR4-mkII-12V-DO-NOT-BUILD-v03.brd, Shruthi-Analog-SMR4-mkII-12V-DO-NOT-BUILD-v03.sch, Shruthi-Digital-v08.brd]

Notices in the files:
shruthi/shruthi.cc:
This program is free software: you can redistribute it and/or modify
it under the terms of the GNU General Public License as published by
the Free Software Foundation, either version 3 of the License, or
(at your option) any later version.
